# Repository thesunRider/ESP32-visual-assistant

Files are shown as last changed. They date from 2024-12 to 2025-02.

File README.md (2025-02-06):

# ESP32 AI portable visual-assistant  
### Device Design Requirements:

1. **Audio Playback:**
   - Play audio through a speaker using the Audio BFF amplifier.
   - Include necessary components for driving the speaker.

2. **Battery Charging:**
   - Support rechargeable Li-ion/Li-poly battery integration with efficient charging and power management.
   - Include a charging circuit and IC for managing charging and power distribution to the ESP32-S3.

3. **Connectivity:**
   - Enable Wi-Fi and Bluetooth (including BLE) for app connectivity and efficient power use.

4. **Camera Integration:**
   - Integrate an OV2640 camera module for image and video capture.

5. **Microphone and Control:**
   - Include three tactile buttons for microphone control with LED feedback for status (e.g., mute/unmute).

6. **Enclosure:**
   - Design a compact, 3D-printed enclosure with ports (e.g., USB charging) and provisions for heat dissipation.

# Final Product:
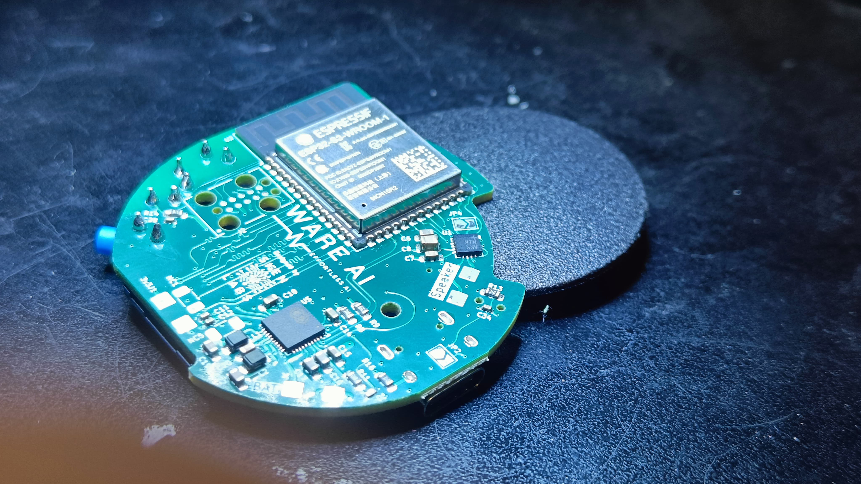
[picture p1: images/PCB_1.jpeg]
PCB_1

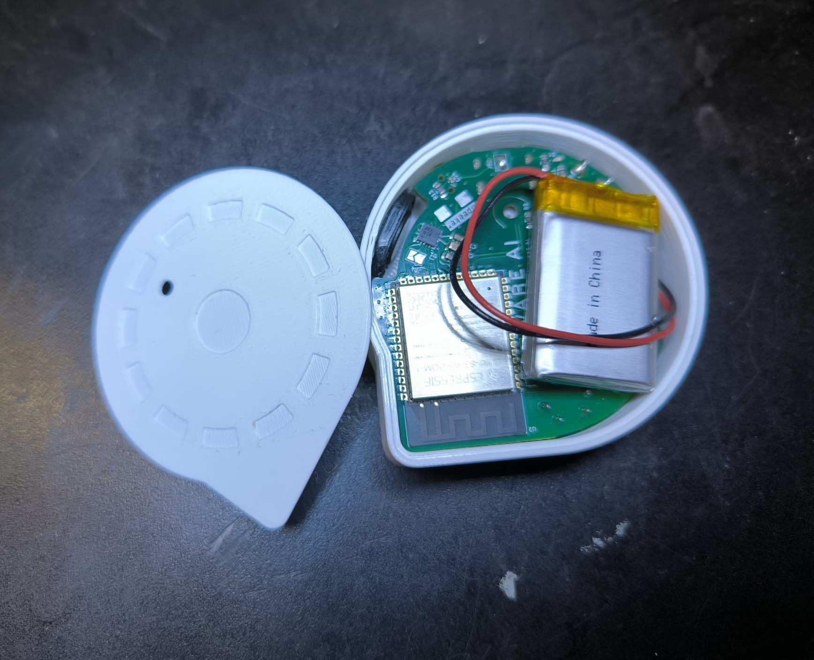
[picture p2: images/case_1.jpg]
Case_1


## Technicals
Language: C++ -> Need to create testcases for harware \
Folder Structure :
- Kicad
	- Test (First Prototype)
	- Main (Main Prototype)
- Docs
	- Datasheets
	- Images
- Gerbers

## Technology Used
Listing of Technologies used in the design:
- PMIC - [AXP2101](https://jlcpcb.com/partdetail/x_powersTech-AXP2101/C3036461) 
- Amplifier & Speaker  - [Max98357 Amplifier](https://learn.adafruit.com/adafruit-max98357-i2s-class-d-mono-amp/overview)
- Switches -
- Camera - [OV5640](https://www.waveshare.com/ov5640-camera-board-a.htm)
- Microphone - [Mems Mic](https://learn.adafruit.com/adafruit-i2s-mems-microphone-breakout/)
- Main Unit - [ESP32-S3-WROOM-1-N4](https://www.digikey.de/de/products/detail/espressif-systems/ESP32-S3-WROOM-1-N4/16163950)

## Flowchart

## Energy Charts

While connecting the amplifier , the supply to the amp should go just after the fuel gauge and the over current protection circuit 

| Component | Voltage  | Current  |
|---|---|---|
| Esp32 S3  | 3v3	 | 650mA |
| Mic | 3v3 | 2mA |
| Amp | 3v7 | 500mA |
| Camera | 3v3 , 2v8, 1v5 | 200mA |
| LED 		| 3v3	| 70mA	|
| Extras |3v3 |30mA|

Max current: 1.5A

## Notes
1. Kindly create a seperate page for each new design block (power, camera,mic,...etc) in kicad
2. Kindly Name no connect jumpers as 0ohm resistors and reference as NC
3. BE CAREFUL TO PLACE NC RESISTORS ISOLATED IN FOOTPRINT AS THEY NEED TO BE DESOLDERED OR SOLDERED WITHOUT DISTURBING SURROUNDINGS
4. Refer [Design Considerations](DesignConsideration.md) for specific module requirements
5. Crossrefer pinconnections between footprint and datasheet to check if they are the same.
6. CHECK IF ALL I2S, I2C , SPI AND SDA INTERFACES HAVE PROPER PULLUPS INSTALLED ON SCHEMATIC
7. Breakout a JTAG controller for debugging esp32

## TODO
- [x] Create Kicad Project
- [x] Make BMC and Avail power Rails
- [x] Craete Flowchart
- [x] Create Esp32 Base 
- [x] Create Amp Schematic
- [x] Create Mic Schematic
- [x] Create Camera Schematic - Created a symbol in Kicad for testing (proceeding with it - need reverse engineer testing)
- [x] Add switch Schematic
- [x] Link Components to PCB 
- [x] Test Cases for Hardware

Project Finished Rev2 Board created with superior perfomance

## Reference
Kindly put circuit reference here
1. USB from here: https://github.com/jenschr/USB-C-Connectors
2. PMIC Reference Design https://oshwhub.com/mondraker/axp2101_2023-11-18_20-15-19

## Components Sourcing
Adafruit OV5640 Camera Breakout
-  Breakout Board uses FD5640 500W Camera sensor
-  Available in bluk from Aliexpress
- Switch: K2-1114SA-A4SW-06, https://jlcpcb.com/partdetail/OmronElectronics-B3S1000/C2733655 Check pin configs
- Switch: K2-1114SA-A4SW-06, https://jlcpcb.com/partdetail/OmronElectronics-B3S1000/C2733655
- Speakers , https://www.lcsc.com/product-detail/Speakers_INGHAi-GSPK151035PN-8R0-5W-L35-1-25T_C530539.html
- Tactile Switches https://de.aliexpress.com/item/32912259140.html?gatewayAdapt=glo2deu

AXP2101 Component
- Inductor   3.1A 1uH ±20% 0806 Power Inductors ROHS
  https://www.lcsc.com/product-detail/Power-Inductors_Chilisin-Elec-HEI201610K-1R0M-Q8DG_C329576.html

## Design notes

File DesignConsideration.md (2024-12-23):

## Design Considerations
Here we specify all steps to produce each modules

## Technology Used
Listing of Technologies used in the design:
- ChargingBMC (PMIC) - [AXP2101](https://jlcpcb.com/partdetail/x_powersTech-AXP2101/C3036461) 
- Overvoltage Current protection
- Amplifier & Speaker  - [Max98357 Amplifier](https://learn.adafruit.com/adafruit-max98357-i2s-class-d-mono-amp/overview)
- Switches -
- Camera - OV5640 
- Microphone - [Mems Mic](https://learn.adafruit.com/adafruit-i2s-mems-microphone-breakout/)
- Main Unit - [ESP32-S3-WROOM-1-N4](https://www.digikey.de/de/products/detail/espressif-systems/ESP32-S3-WROOM-1-N4/16163950)

### ESP32 Module 
Unit: **ESP32-S3-WROOM-1-N4** \
JLCPCB: Not Available \
Logic levels ESP32 - VDD x 0.75 H : VDD x 0.25 L \
Max 650 mA at 3.3V input 

- Soldering the EPAD to the ground of the base board is not a must, however, it can optimize thermal
performance. If you choose to solder it, please apply the correct amount of soldering paste. Too much
soldering paste may increase the gap between the module and the baseboard. As result, the adhesion
between other pins and the baseboard may be poor.

- To ensure that the power supply to the ESP32-S3 chip is stable during power-up, it is advised to add an
RC delay circuit at the EN pin. The recommended setting for the RC delay circuit is usually R = 10 kΩ and
C = 1 µF. However, specific parameters should be adjusted based on the power-up timing of the module
and the power-up and reset sequence timing of the chip. For ESP32-S3’s power-up and reset sequence
timing diagram, please refer to ESP32-S3 Series Datasheet > Section Power Supply

For booting after reset:

| Boot Mode | GPIO0  | GPIO46  |
|---|---|---|
| SPI Boot  | 1	 | Any |
| Joint Boot | 0 | 0 |

SPI Boot - Loads from internal memory and executes (default)
Joint Boot - In Joint Download Boot mode, users can download binary files into flash using UART0 or USB interface. It is
also possible to download binary files into SRAM and execute it from SRAM (Programming)

#### Warning
- IO47/IO48 operates in the 1.8V voltage domain.

## Microphone Module
Unit: ICS-43434 \
JLCPCB: Available \
Logic Levels: VDD x 0.7 H : VDD x 0.3 L \
Max 1mA at 3.3V \
I2S unit with full itegrated components 

Refer App notes \
Refer Schematic at: https://learn.adafruit.com/assets/132616 \

### Warning
- SD Output Serial	Data Output	for	I²S	Interface.	This	pin	tristates	when	not	actively	driving	the	
appropriate	output	channel.	The	SD	trace	should	have	a	100	kΩ	pull-down	resistor	to	
discharge	the	line	during	the	time that	all	microphones	on	the	bus	have	tristated	their	
outputs.	

### Interfacing
ESP32-S3 includes two standard I2S interfaces. They can operate in master mode or slave mode, in full-duplex mode or half-duplex communication mode, and can be configured to operate with an 8-bit, 16-bit, 24-bit, or 32-bit resolution as an input or output channel. BCK clock frequency, from 10 kHz up to 40 MHz, is supported.

The I2S interface has a dedicated DMA controller. It supports TDM PCM, TDM MSB alignment, TDM LSB alignment, TDM Phillips, and PDM interface.
Pin Assignment:
For I2S, the pins used can be chosen from any GPIOs via the GPIO Matrix. For more information about the pin assignment, see ESP32-S3 Series Datasheet > Section IO Pins and ESP32-S3 Technical Reference Manual > Chapter IO MUX and GPIO Matrix.

## Amplifier and Speaker
Unit: MAX98357 \ 
JLCPCB: Available \
Logic Levels: 1.3 H : 0.6V L \
Max 500mA at 3.7V 

I2S unit with full itegrated components \
The gain of the unit depends on the Resistor connected to Gainslot

| GAIN_SLOT |  I2S/LJ GAIN (dB)  |
|---|---|
| Connect to GND through 100kΩ  | 15	 | 
| Connect to GND  | 12 | 
|Unconnected|9|
|Connect to VDD|6|
|Connect to VDD through 100kΩ|3|

Try changing NC2 according table above to increase/decrease gain

### Warning
The amplifier only TAKES LEFT CHANNEL \

## Camera 
Unit: OV5640 \
JLCPCB: Not available \
Logic Levels: 2.8V \
core: 1.5V ± 5% (with embedded 1.5V regulator) \
analog: 2.6 ~ 3.0V (2.8V typical) \
I/O: 1.8V / 2.8V \
Power: active: 140 mA 

Connector : 24 Pin 0.5mm Pitch Bottom Contact ZIF Connector,FPC Connector - https://www.buydisplay.com/24-pin-0-5mm-pitch-bottom-contact-zif-connector-fpc-connector

### Warning: 
While connecting camera module there are a lot of unconnected jumpers ,while testing check if we need connection by refering schematic (BUY 0ohm resisors) 

## Charging and PMIC
Unit: AXP2101 \
JLCPCB: available \
Logic level: 3.3V 

## Color LED 
Unit: WS2812B \
JLCPCB: Avaialble \
Logic Level: 0.7 x VCC H : 0.3 x VCC L \
Min 3.5V with 60mA \

## ESD Protection
Status Pending

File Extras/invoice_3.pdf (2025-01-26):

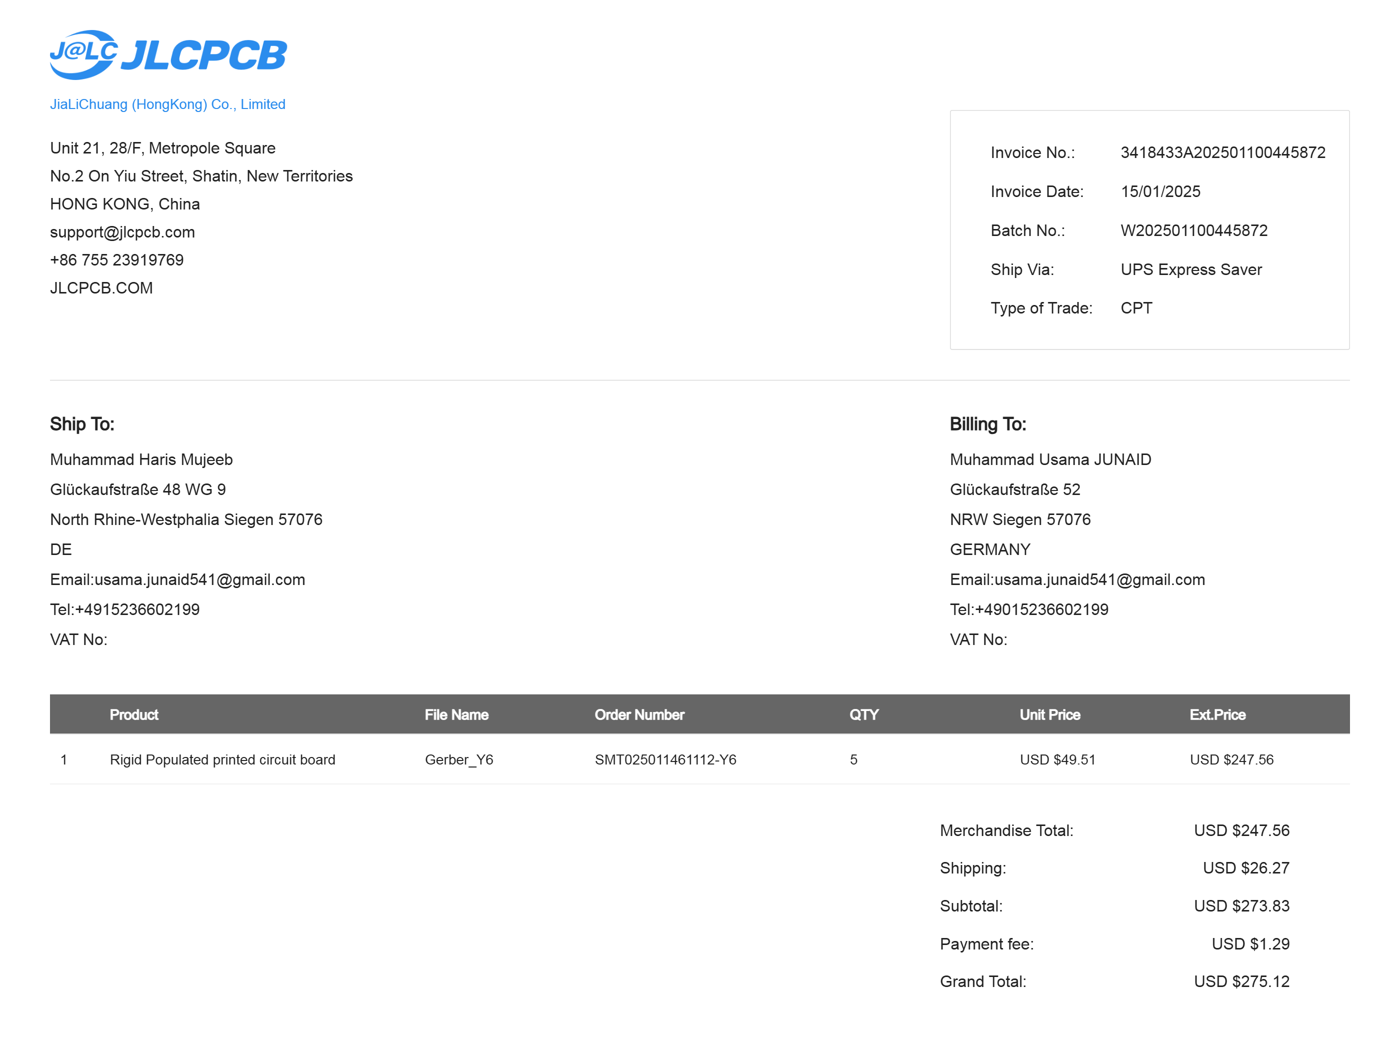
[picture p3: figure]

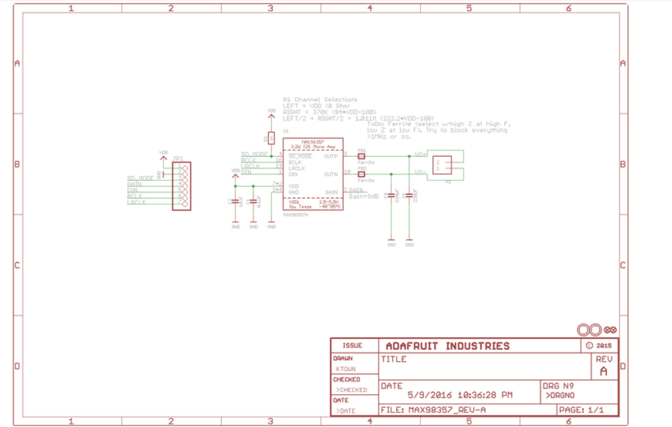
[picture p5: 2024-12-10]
Docs/Reference Schematic/max98357A.PNG

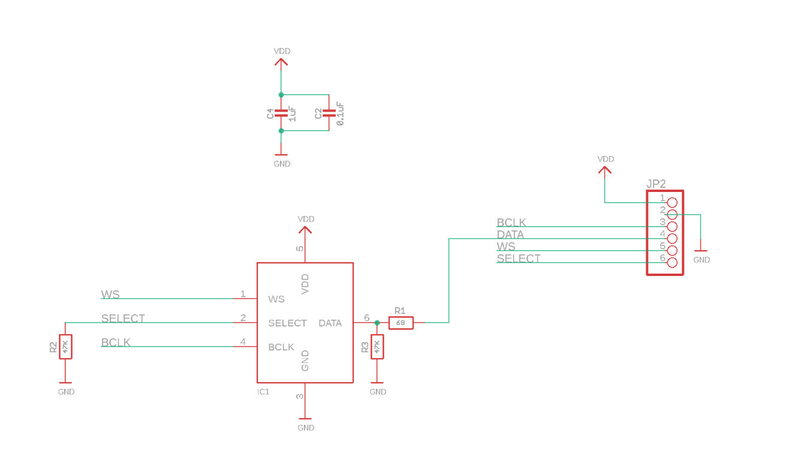
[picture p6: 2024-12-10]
Docs/Reference Schematic/ics43434.PNG

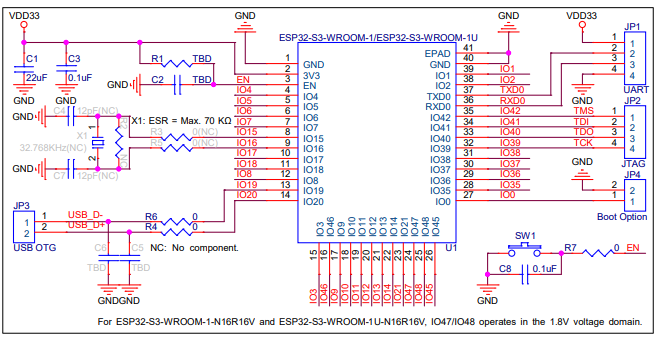
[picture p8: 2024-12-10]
Docs/Reference Schematic/esp32s3_peripherals.PNG

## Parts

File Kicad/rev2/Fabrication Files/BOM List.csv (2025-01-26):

null | Designator | Value | Footprint | Description | LCSC Part # | Mfr Part | Quantity
1 | C10, C11, C12, C13, C27, C28, C29, C30, C31, C34 | 100n | C_0402_1005Metric | Unpolarized capacitor | C1525 | CL05B104KO5NNNC | 10 | 16V 100nF X7R ±10% 0402 Multilayer Ceramic Capacitors MLCC - SMD/SMT ROHS
2 | C2, C4, C6, C16, C17, C19, C22 | 22u | C_0603_1608Metric_Pad1.08x0.95mm_HandSolder | Unpolarized capacitor | C59461 | CL10A226MQ8NRNC | 7 | 6.3V 22uF X5R ±20% 0603 Multilayer Ceramic Capacitors MLCC - SMD/SMT ROHS
3 | C15, C18, C20, C21,C23, C25, C26, | 10u | C_0603_1608Metric_Pad1.08x0.95mm_HandSolder | Unpolarized capacitor | C19702 | CL10A106KP8NNNC | 6 | 10V 10uF X5R ±10% 0603 Multilayer Ceramic Capacitors MLCC - SMD/SMT ROHS
4 | C3, C5, C7 | 0.1u | C_0603_1608Metric_Pad1.08x0.95mm_HandSolder | Unpolarized capacitor | C14663 | CC0603KRX7R9BB104 | 3 | 50V 100nF X7R ±10% 0603 Multilayer Ceramic Capacitors MLCC - SMD/SMT ROHS
5 | C9, C33 | 15p | C_0402_1005Metric | Unpolarized capacitor | C1548 | 0402CG150J500NT | 2 | 50V 15pF C0G ±5% 0402 Multilayer Ceramic Capacitors MLCC - SMD/SMT ROHS
6 | C1, C14, C24 | 1u | C_0603_1608Metric | Unpolarized capacitor | C15849 | CL10A105KB8NNNC | 3 | 50V 1uF X5R ±10% 0603 Multilayer Ceramic Capacitors MLCC - SMD/SMT ROHS
7 | C8 | 100u | C_0603_1608Metric_Pad1.08x0.95mm_HandSolder | Unpolarized capacitor | C141660 | GRM21BR60J107ME15L | 1 | 6.3V 100uF X5R ±20% 0805 Multilayer Ceramic Capacitors MLCC - SMD/SMT ROHS
9 | R1, R8, R9, R12, R13, R14, R15 | 10k | R_0603_1608Metric_Pad0.98x0.95mm_HandSolder | Resistor | C25804 | 0603WAF1002T5E | 7 | 100mW Thick Film Resistors 75V ±100ppm/? ±1% 10k? 0603 Chip Resistor - Surface Mount ROHS
10 | R2, R3 | 47k | R_0603_1608Metric_Pad0.98x0.95mm_HandSolder | Resistor | C25819 | 0603WAF4702T5E | 2 | 100mW Thick Film Resistors 75V ±100ppm/? ±1% 47k? 0603 Chip Resistor - Surface Mount ROHS
11 | R7, R10 | 4.7k | R_0603_1608Metric_Pad0.98x0.95mm_HandSolder | Resistor | C23162 | 0603WAF4701T5E | 2 | 100mW Thick Film Resistors 75V ±100ppm/? ±1% 4.7k? 0603 Chip Resistor - Surface Mount ROHS
12 | R4 | 68 | R_0603_1608Metric_Pad0.98x0.95mm_HandSolder | Resistor | C27592 | 0603WAF680JT5E | 1 | 100mW Thick Film Resistors 75V ±100ppm/? ±1% 68? 0603 Chip Resistor - Surface Mount ROHS
13 | R11 | 1k | R_0603_1608Metric_Pad0.98x0.95mm_HandSolder | Resistor | C21190 | 0603WAF1001T5E | 1 | 100mW Thick Film Resistors 75V ±100ppm/? ±1% 1k? 0603 Chip Resistor - Surface Mount ROHS
14 | R16 | 1M | R_0603_1608Metric_Pad0.98x0.95mm_HandSolder | Resistor | C22935 | 0603WAF1004T5E | 1 | 100mW Thick Film Resistors 75V ±100ppm/? ±1% 1M? 0603 Chip Resistor - Surface Mount ROHS
15 | L1, L2 | 1u | L_0805_2012Metric_Pad1.05x1.20mm_HandSolder | Inductor | C6364721 | AHW2012F-1R0KTF | 2 | 430mA 1uH ±10% 1? 0805 Inductors (SMD) ROHS
16 | D1 | LED | LED_0402_1005Metric | Light emitting diode | C965793 | XL-1005UGC | 1 | 25mA 249mcd Colorless transparent lens -30?~+85? Positive Stick 516nm~531nm Emerald 120° 80mW 3V 0402 LED Indication - Discrete ROHS
17 | D4 | WS2812B | LED_WS2812B_PLCC4_5.0x5.0mm_P3.2mm | RGB LED with integrated controller | C22461793 | XL-5050RGBC-WS2812B-S | 1 | SMD-4P,5x5mm RGB LEDs(Built-in IC) ROHS
18 | U1 | MAX98357A | TQFN-16-1EP_3x3mm_P0.5mm_EP1.23x1.23mm | Monaural 3.2Wx2@4Î© BGA-9(1.3x1.3) Audio Amplifiers ROHS | C2682619 | MAX98357AEWL+T | 1
19 | U2 | ESP32-S3-WROOM-1 | ESP32-S3-WROOM-1 | RF Module, ESP32-S3 SoC, Wi-Fi 802.11b/g/n, Bluetooth, BLE, 32-bit, 3.3V, onboard antenna, SMD | C2913205 |  | 1
20 | U3 | OV5640 | TE_2-1734839-4_1x24-1MP_P0.5mm_Horizontal | Flip type 24P Bottom Contact Horizontal attachment 0.5mm SMD,P=0.5mm,Surface Mountï¼ŒRight Angle FFC, FPC (Flat Flexible) Connector Assemblies ROHS | C262669 | AFC01-S24FCA-00 | 1
21 | U4 | 24Mhz | YSO110TR | 1.8V~3.3V Â±10ppm 4mA Â±20ppm CMOS 24MHz SMD2520-4P Crystal Oscillators ROHS | C669072 | OT252024MJBA4SL | 1
22 | U5 | AXP2101 | QFN-40-1EP_5x5mm_P0.4mm_EP3.6x3.6mm | QFN-40-EP(5x5) Power Management - Specialized ROHS | C3036461 | AXP2101 | 1
23 | SW1, SW2 | SW_Push | SW2_1825027-C_TEC | 3.25mm Round Button 50mA Bend-in SPST 160gf 24V Plugin Tactile Switches ROHS | C266196 | 1825027-8 | 2
24 | SW4 | SW_Push | K2-1114SA-A4SW-06 | 3.5mm 1.65mm Rectangle button 50mA Horizontal attachment 4.8mm SPST 100000 Times 250gf 12V SMD Tactile Switches ROHS | C136662 | K2-1114SA-A4SW-06 | 1
25 | SW5 | SW_Push | SW_SPST_B3S-1000 | Tactile Switches ROHS | C2733655 | B3S-1000 | 1
27 | JP2, JP3, JP4 | Jumper | SolderJumper-2_P1.3mm_Open_TrianglePad1.0x1.5mm | Jumper, 2-pole, open |  |  | 3
28 | NC1, NC3, NC5 | 0 | R_1206_3216Metric | Resistor |  |  | 3
29 | MK2 | ICS-43434 | InvenSense_ICS-43434-6_3.5x2.65mm | Omni-directional 64dB MEMS Microphones ROHS | C5656610 | ICS-43434 | 1
31 | P1 | USB_C_Plug_USB2.0 | USB_C_Receptacle_HRO_TYPE-C-31-M-12 | USB 2.0-only Type-C Plug connector | C2982555 | TYPE-C-31-M-14 | 1

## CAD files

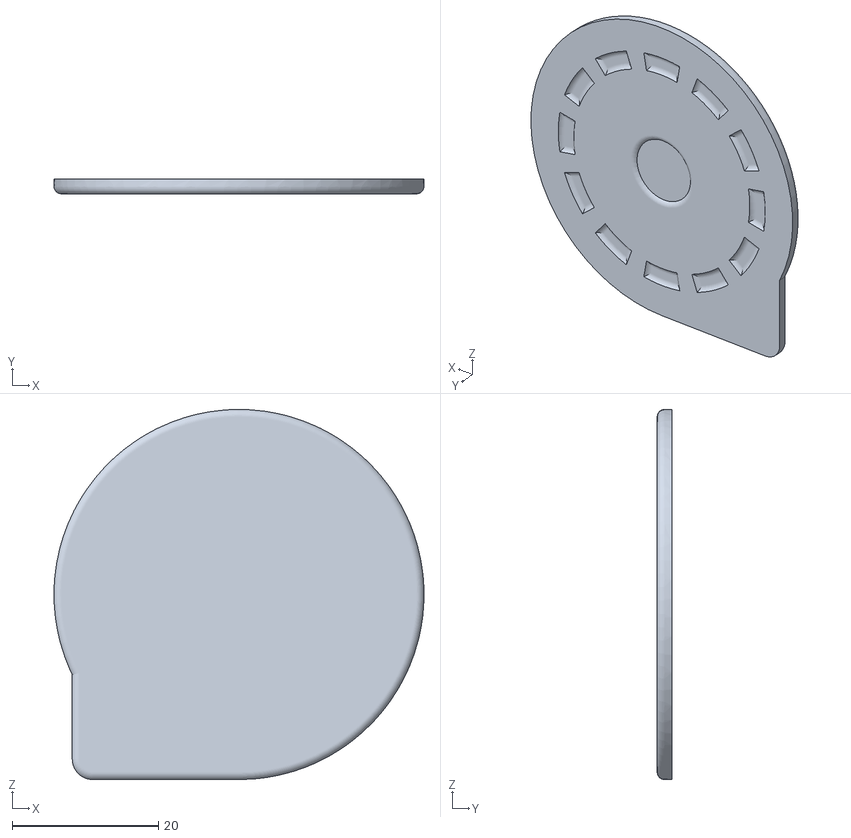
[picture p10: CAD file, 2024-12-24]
3d_model/Casing/Ware_lid.STL
50.6 x 2.00 x 50.6

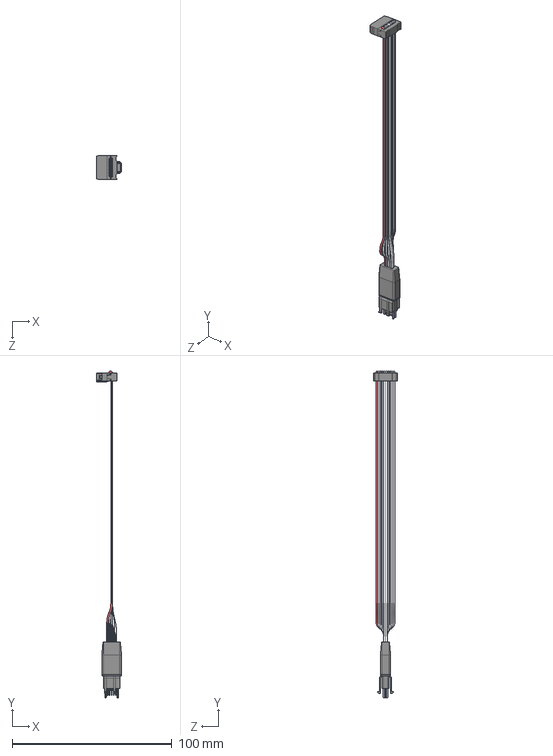
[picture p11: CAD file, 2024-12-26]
3d_model/TC2050-IDC.step
15.7 x 204.4 x 15.2 mm

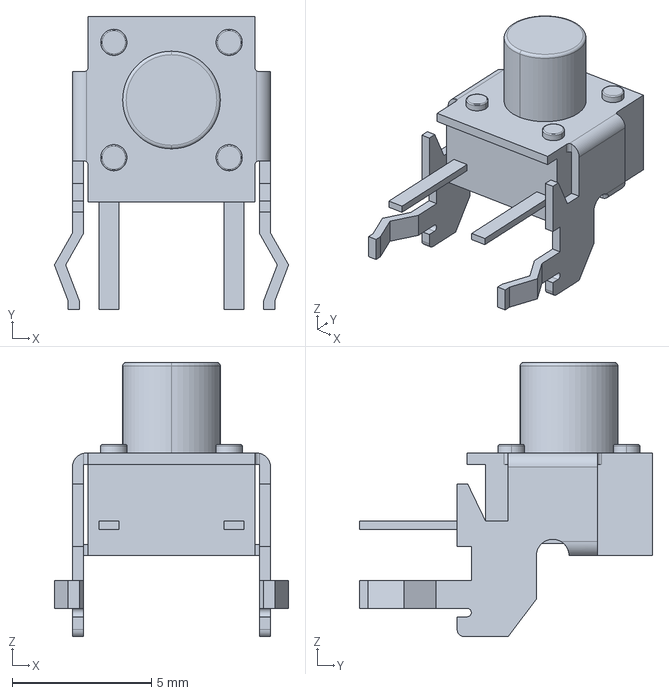
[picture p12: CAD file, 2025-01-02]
Kicad/ImportedComponents/c-1825027-8-g-3d.stp
8.41 x 10.5 x 9.84 mm

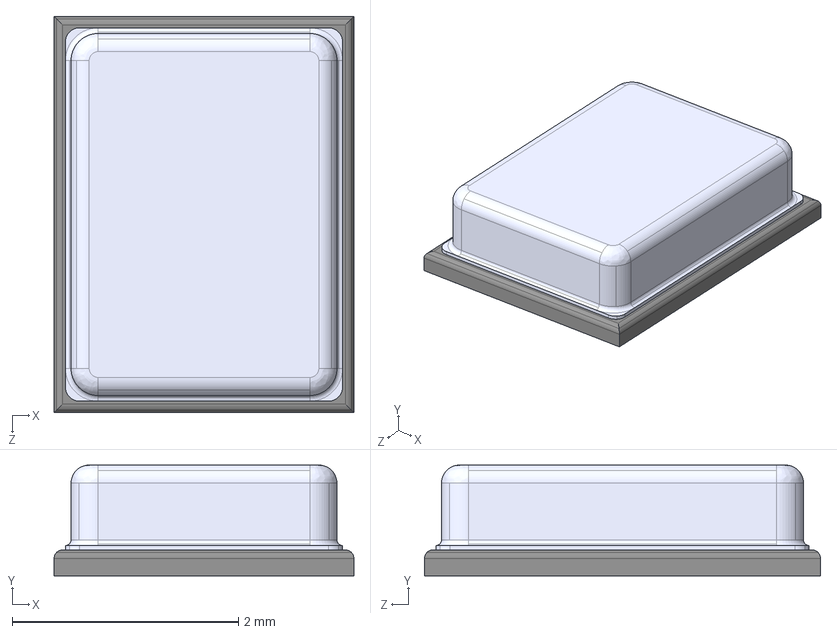
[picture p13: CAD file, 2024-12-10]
Kicad/ImportedComponents/ICS-43434/ICS-43434.step
2.65 x 0.98 x 3.50 mm

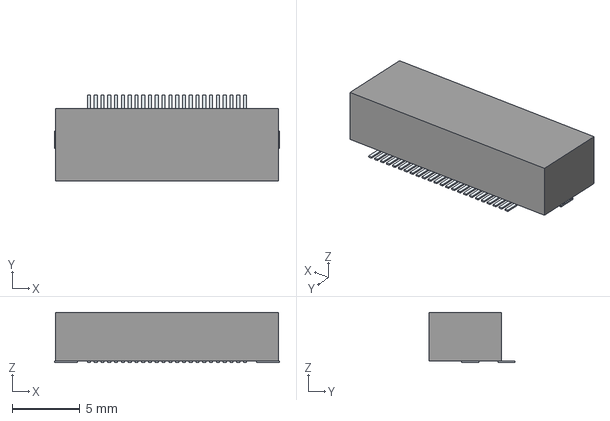
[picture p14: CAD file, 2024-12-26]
3d_model/AFC01-S24FCA-00.stp
16.6 x 6.32 x 3.70 mm
Pins

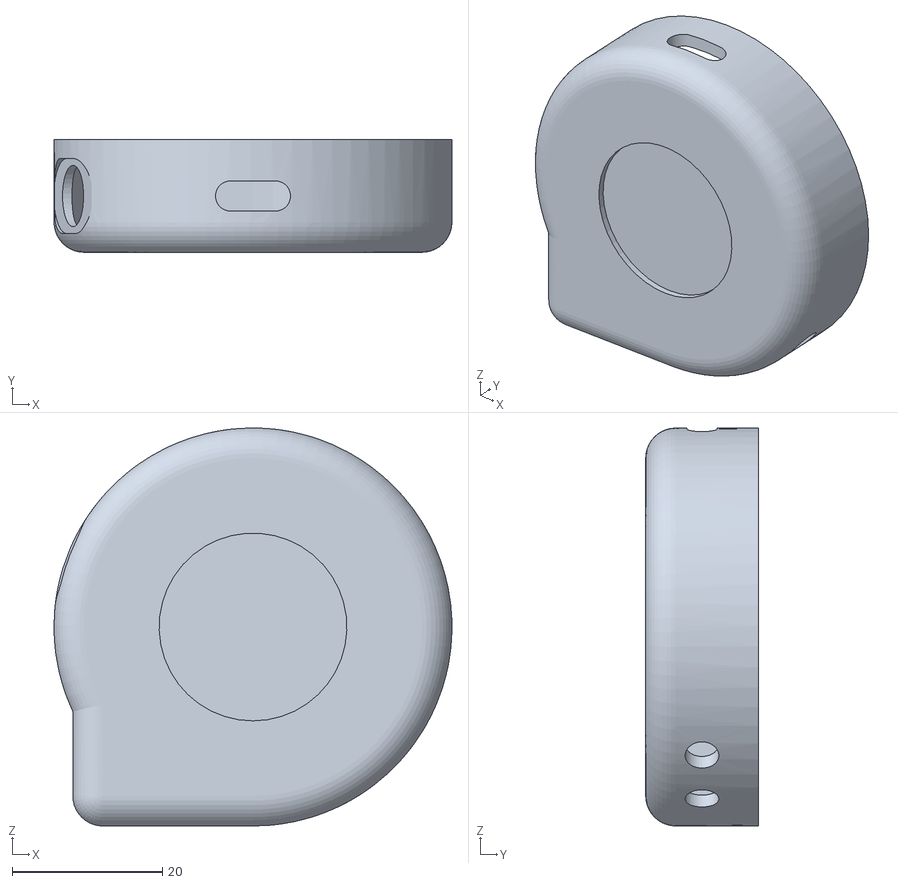
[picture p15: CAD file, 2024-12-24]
3d_model/Casing/Ware_outer_shell.STL
53.0 x 15.0 x 53.0

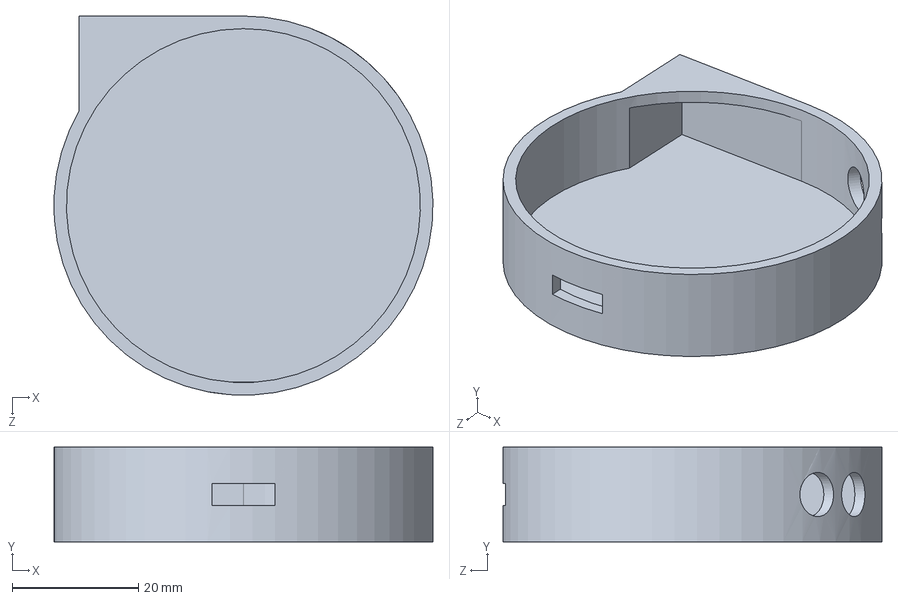
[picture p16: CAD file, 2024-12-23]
3d_model/Ware_outer_shell.SLDPRT
60.0 x 15.0 x 60.0 mm

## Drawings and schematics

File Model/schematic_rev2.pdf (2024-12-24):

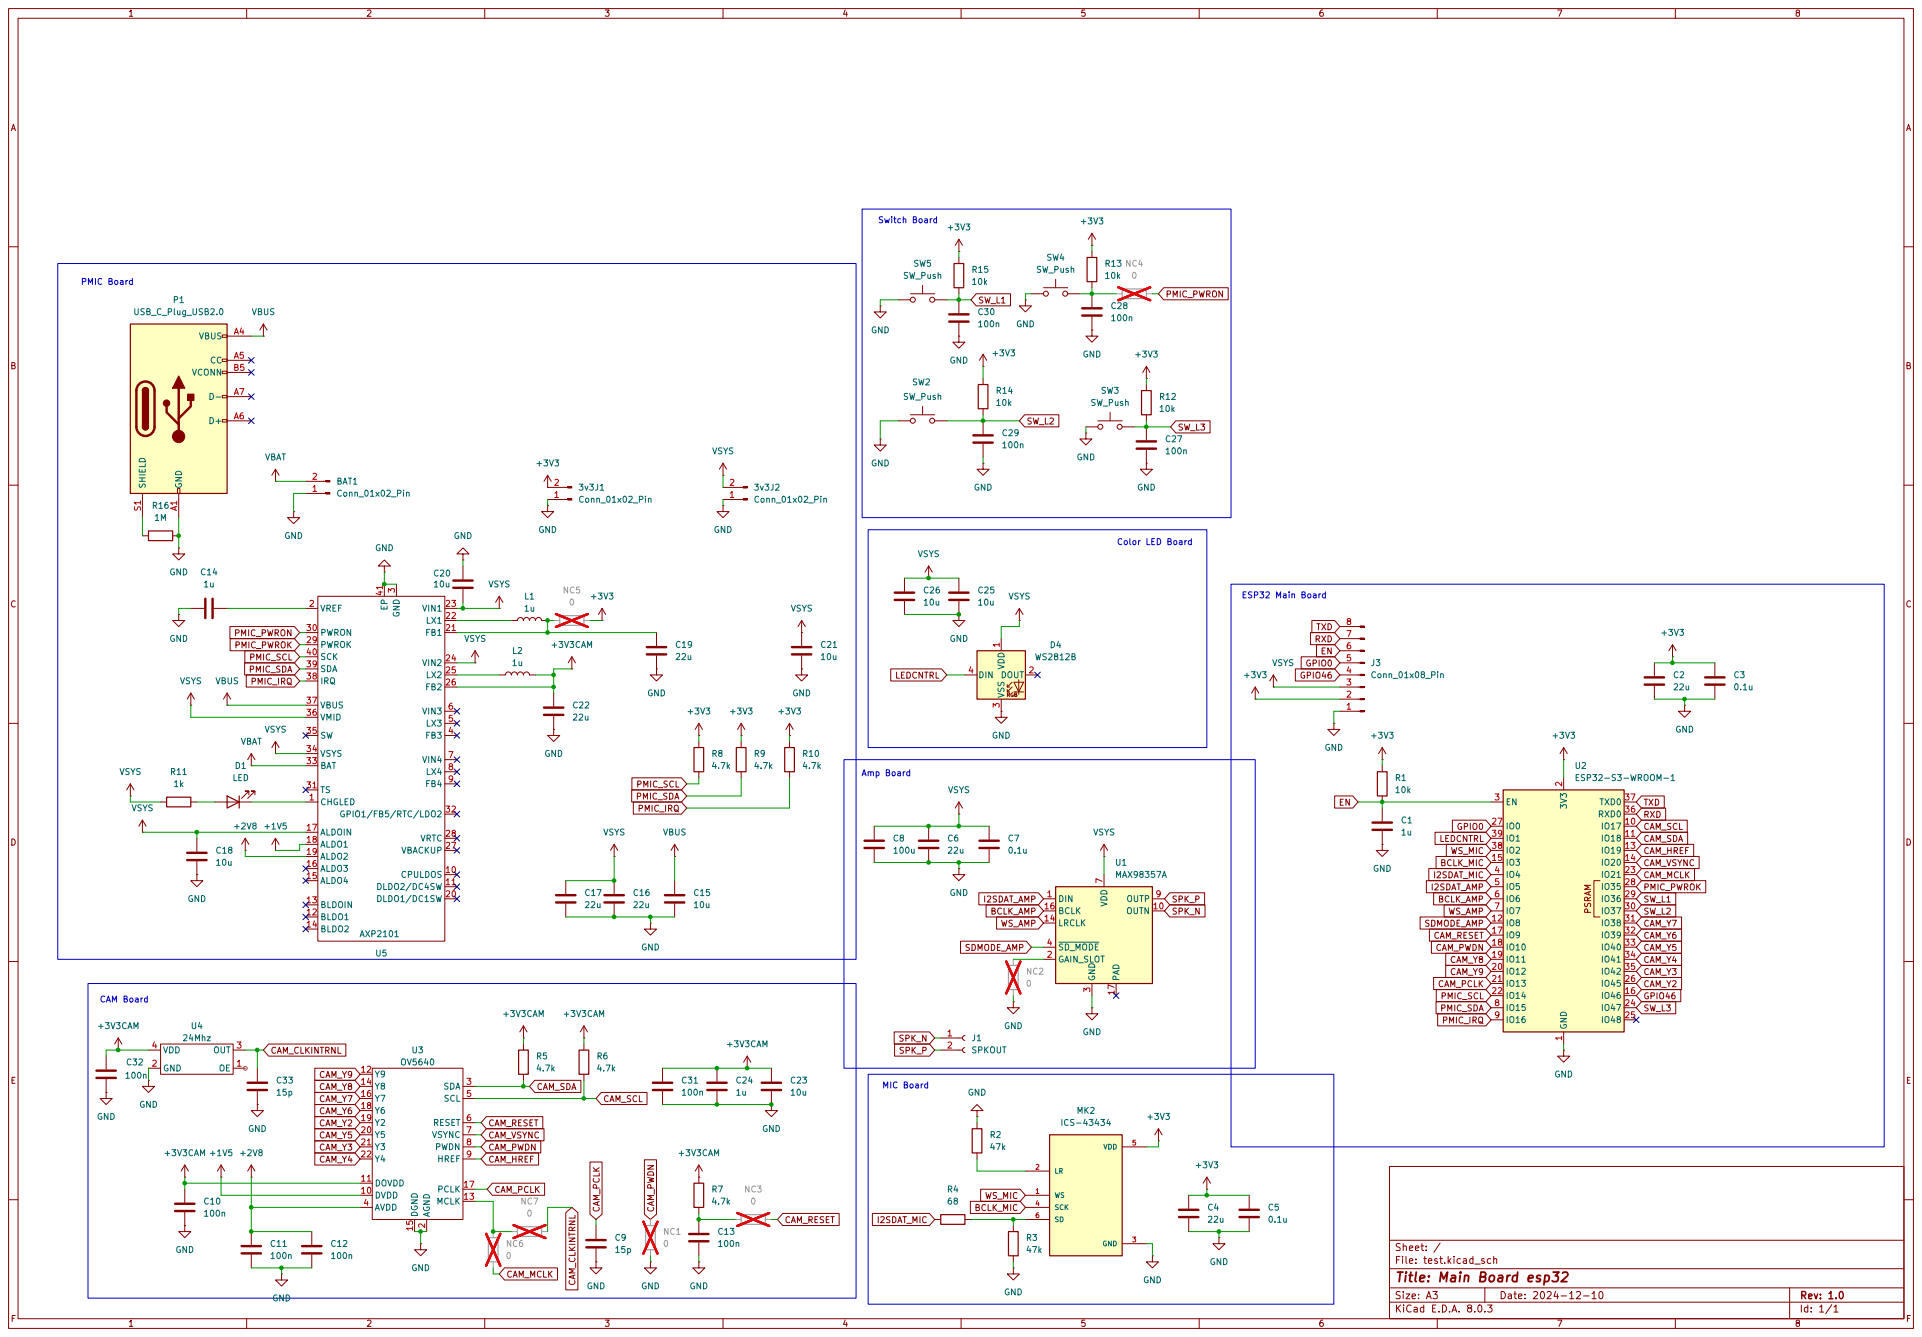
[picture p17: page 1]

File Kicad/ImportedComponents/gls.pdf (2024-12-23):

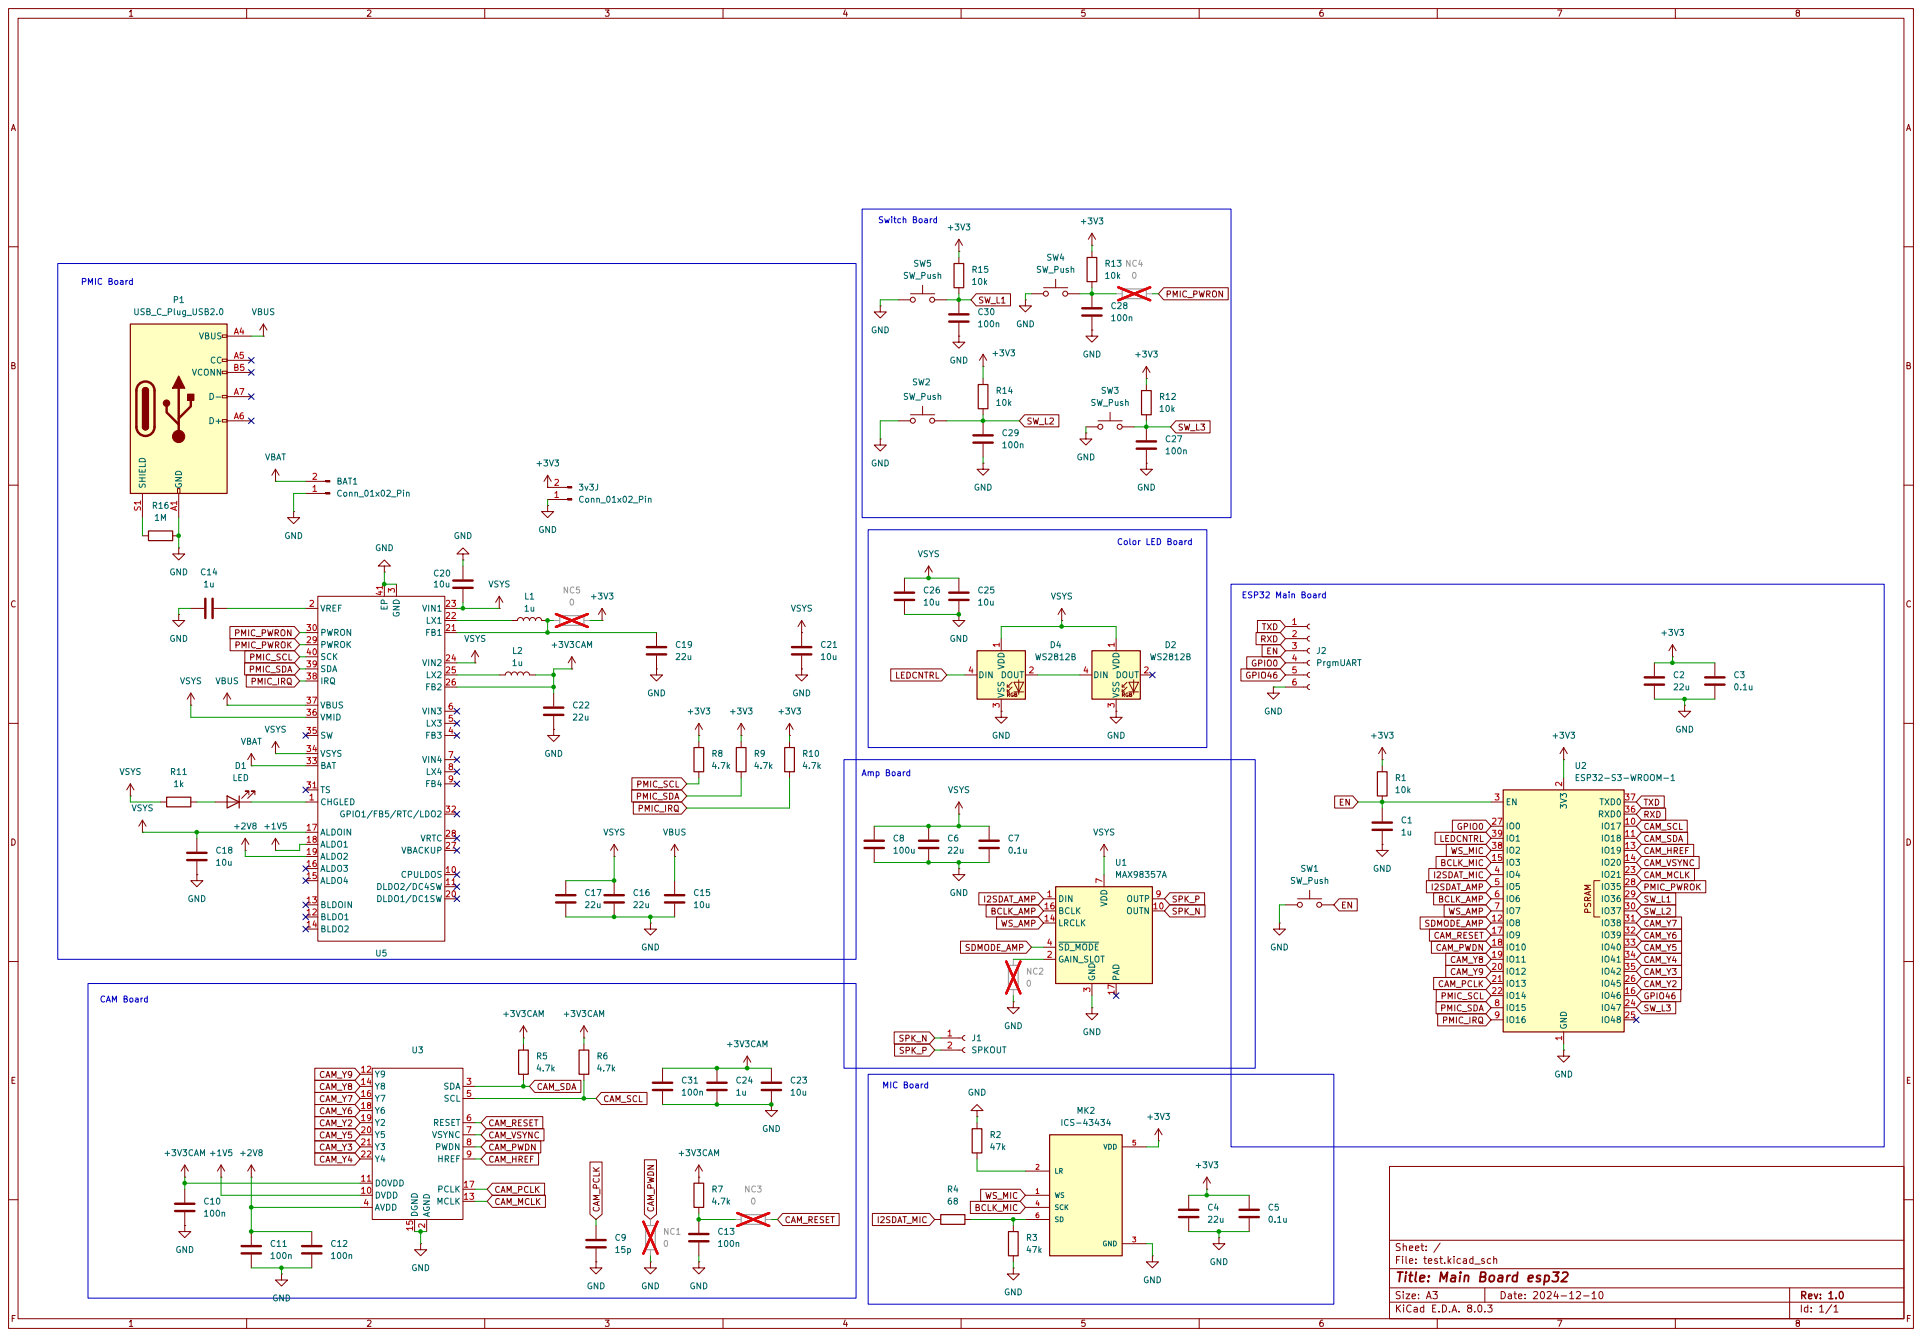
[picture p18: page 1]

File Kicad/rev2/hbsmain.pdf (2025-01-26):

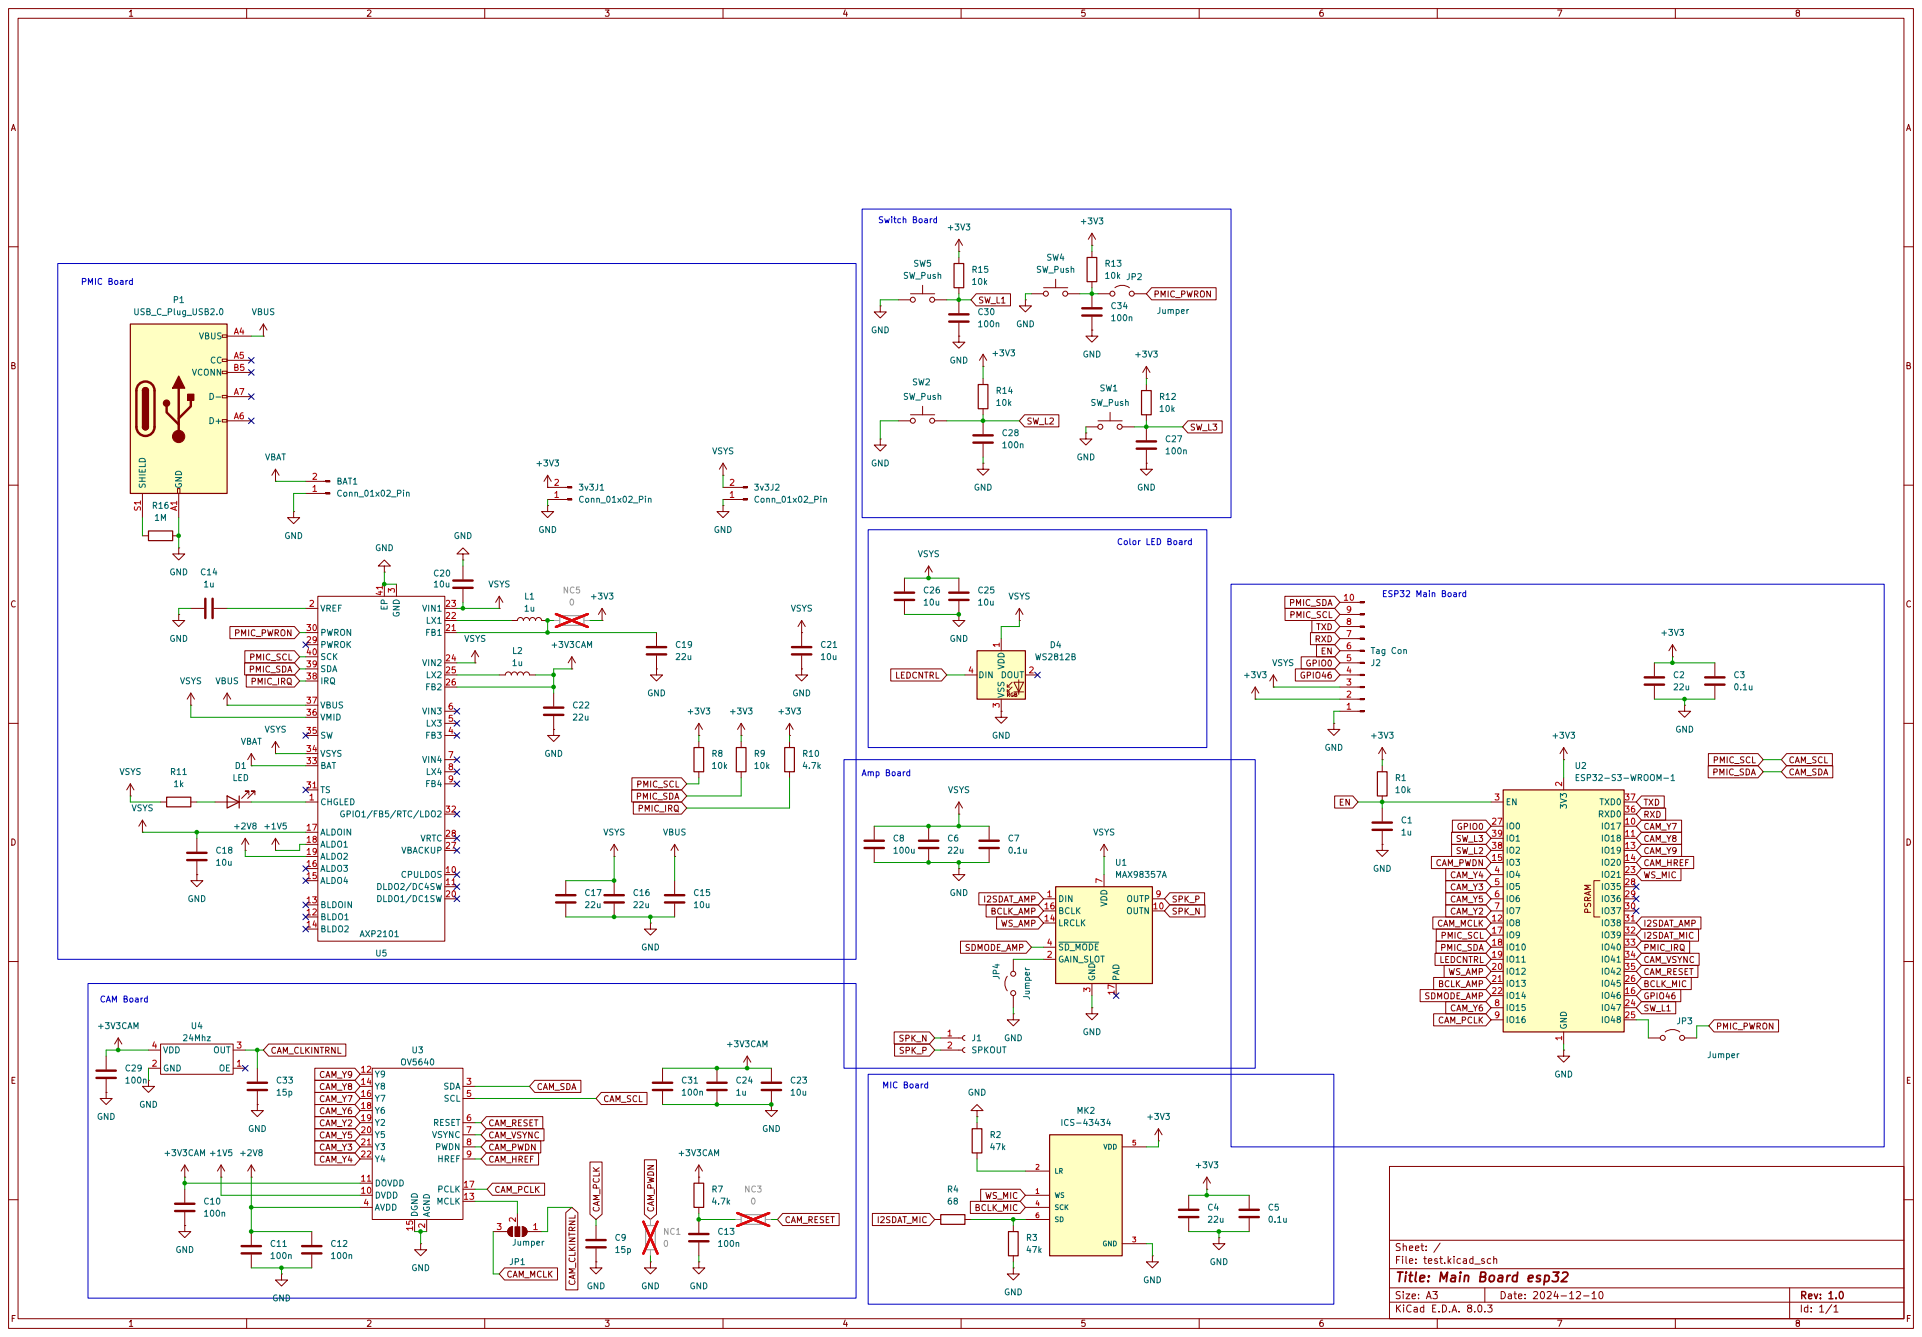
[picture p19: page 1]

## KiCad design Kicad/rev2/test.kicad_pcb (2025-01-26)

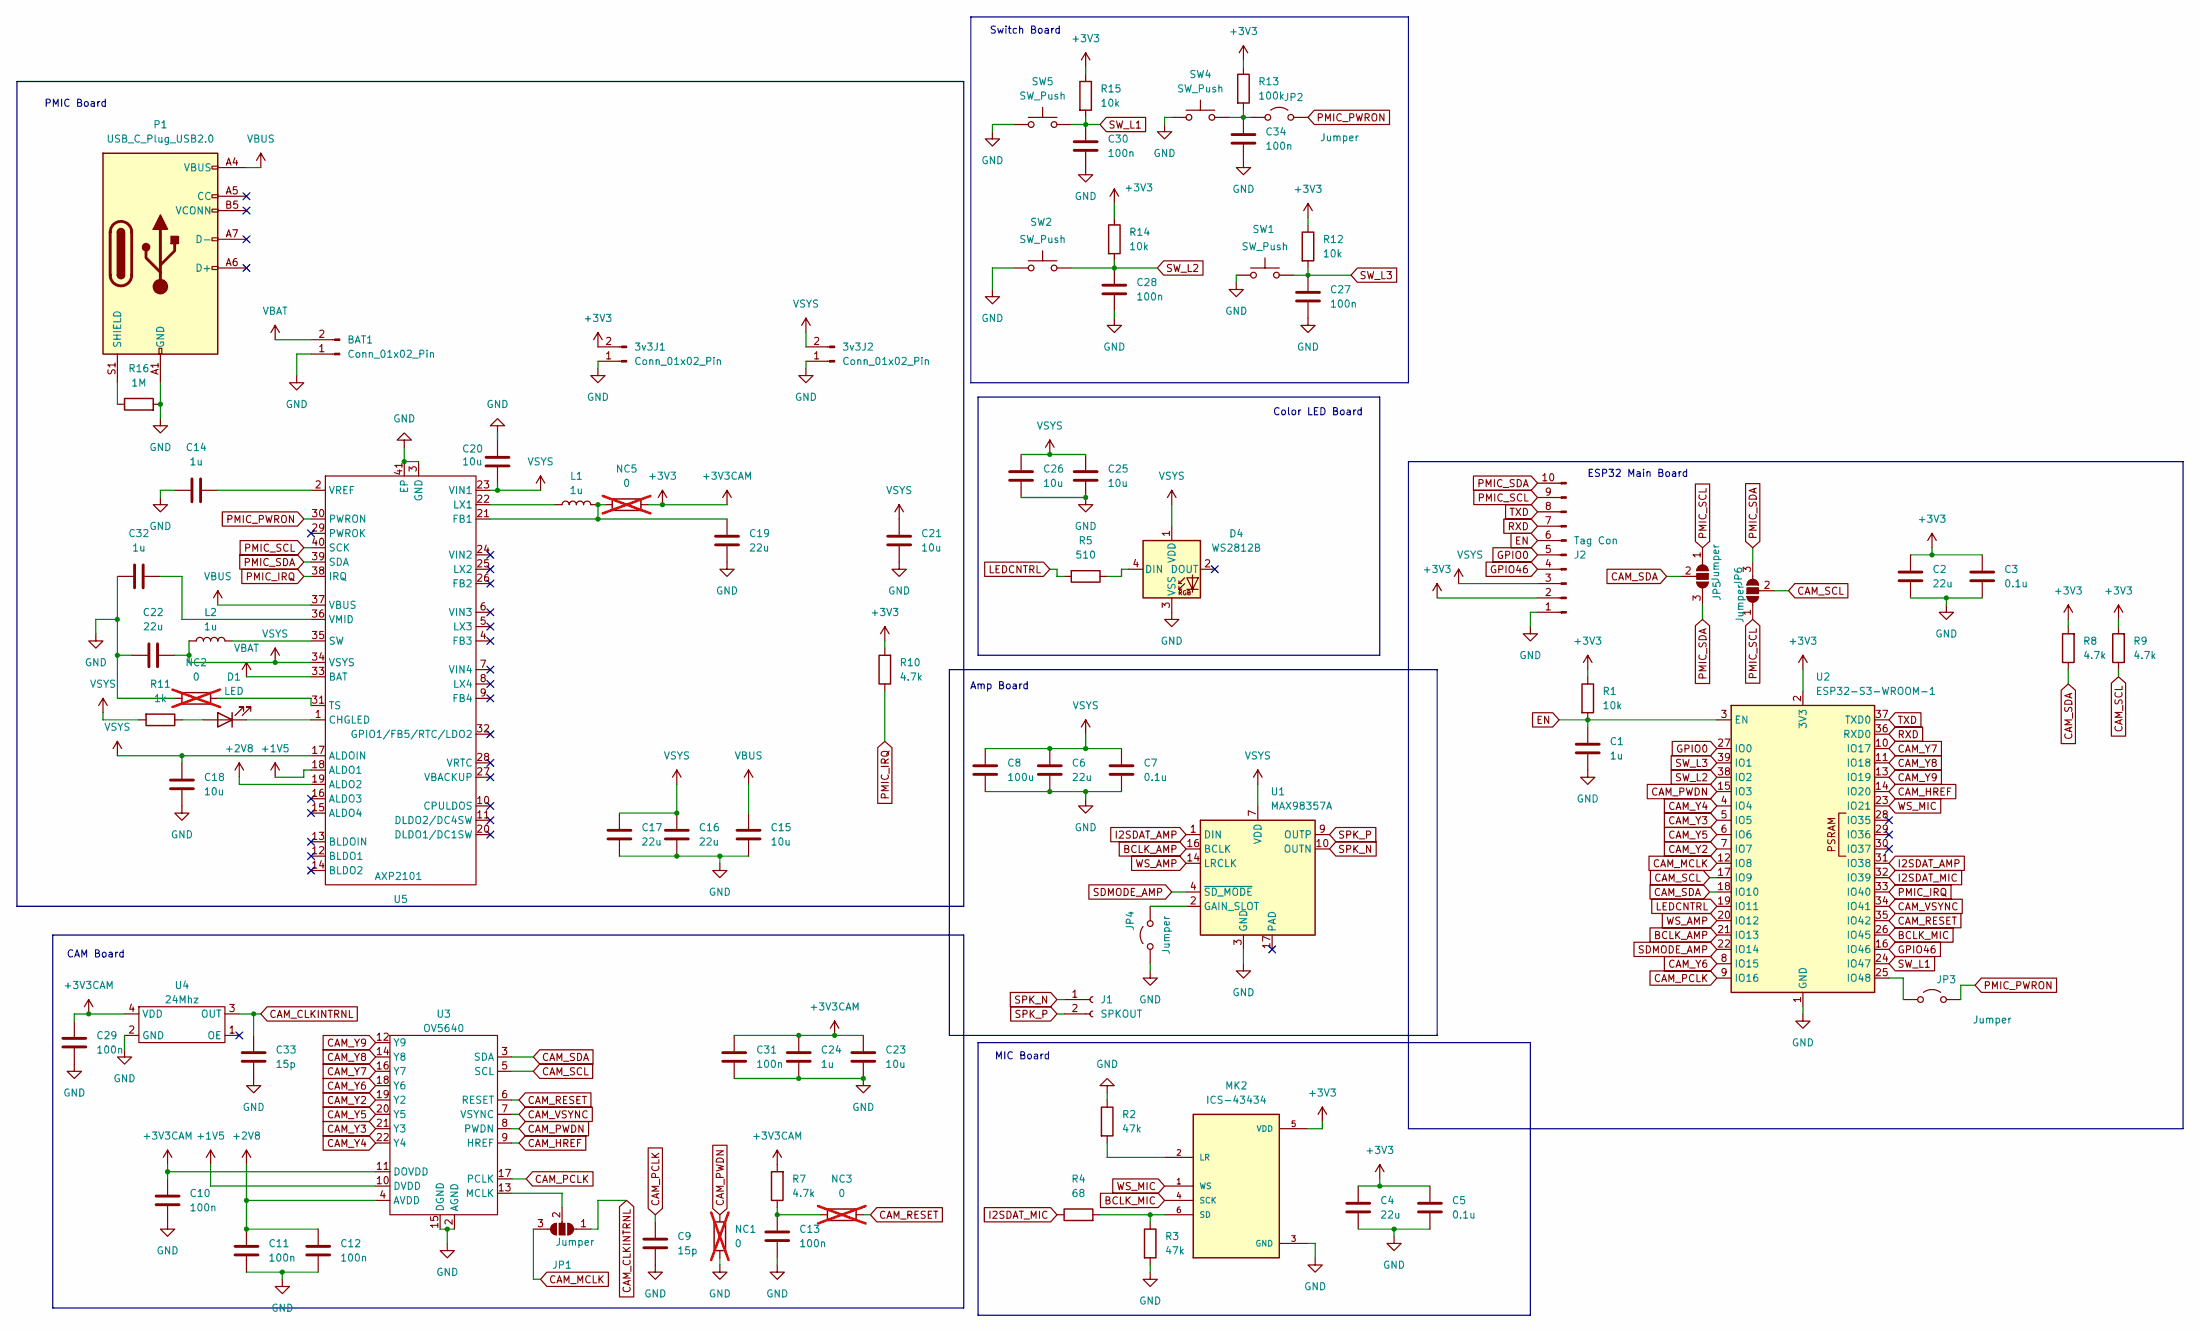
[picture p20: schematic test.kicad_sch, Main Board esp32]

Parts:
3v3J1, 3v3J2: Conn_01x02_Pin; SMD_CONNECTOR_PAD
BAT1: Conn_01x02_Pin; SMD_CONNECTOR_PAD
C1, C14, C24, C32: 1u; C_0603_1608Metric
C2, C4, C6, C16, C17, C19, C22: 22u; C_0603_1608Metric_Pad1.08x0.95mm_HandSolder
C3, C5, C7: 0.1u; C_0603_1608Metric_Pad1.08x0.95mm_HandSolder
C8: 100u; C_0805_2012Metric
C9, C33: 15p; C_0402_1005Metric
C10, C11, C12, C13, C27, C28, C29, C30, C31, C34: 100n; C_0402_1005Metric; Mfr. # CL05B104KO5NNNC; LCSC Part # C1525
C15, C18, C20, C21, C25, C26: 10u; C_0603_1608Metric_Pad1.08x0.95mm_HandSolder
C23: 10u; C_0603_1608Metric
D1: LED; LED_0402_1005Metric
D4: WS2812B; LED_WS2812B_PLCC4_5.0x5.0mm_P3.2mm; Mfr Part XL-5050RGBC-WS2812B-S; LCSC Part C22461793
J1: SPKOUT; SMD_CONNECTOR_PAD
J2: Tag Con; TAG-CONNECT_TC2050-IDC
JP1, JP5, JP6: Jumper; SolderJumper-3_P1.3mm_Open_RoundedPad1.0x1.5mm
JP2, JP3, JP4: Jumper; SolderJumper-2_P1.3mm_Open_TrianglePad1.0x1.5mm
L1, L2: 1u; L_0805_2012Metric_Pad1.05x1.20mm_HandSolder; Mfr Part AHW2012F-1R0KTF; LCSC Part C6364721
MK2: ICS-43434; InvenSense_ICS-43434-6_3.5x2.65mm; Mfr Part ICS-43434; LCSC Part C5656610
NC1, NC2, NC3, NC5: 0; R_1206_3216Metric; not fitted
P1: USB_C_Plug_USB2.0; USB_C_Receptacle_HRO_TYPE-C-31-M-12; Mfr Part TYPE-C-31-M-14; LCSC Part C223907
R1: 10k; R_0603_1608Metric
R2, R3: 47k; R_0603_1608Metric_Pad0.98x0.95mm_HandSolder
R4: 68; R_0603_1608Metric_Pad0.98x0.95mm_HandSolder
R5: 510; R_0603_1608Metric_Pad0.98x0.95mm_HandSolder
R7, R8, R9, R10: 4.7k; R_0603_1608Metric_Pad0.98x0.95mm_HandSolder
R11: 1k; R_0603_1608Metric_Pad0.98x0.95mm_HandSolder
R12, R14, R15: 10k; R_0603_1608Metric_Pad0.98x0.95mm_HandSolder
R13: 100k; R_0603_1608Metric_Pad0.98x0.95mm_HandSolder
R16: 1M; R_0603_1608Metric_Pad0.98x0.95mm_HandSolder
SW1, SW2: SW_Push; SW2_1825027-C_TEC; Mfr Part 1825027-8; LCSC Part C266196
SW4: SW_Push; K2-1114SA-A4SW-06; Mfr Part K2-1114SA-A4SW-06; LCSC Part C136662
SW5: SW_Push; SW_SPST_B3S-1000; Mfr Part B3S-1000; LCSC Part C2733655
U1: MAX98357A; 21-0136I_T1633-4_MXM-M; Mfr Part MAX98357AETE+T; LCSC Part C910544
U2: ESP32-S3-WROOM-1
U3: OV5640; TE_2-1734839-4_1x24-1MP_P0.5mm_Horizontal; Mfr Part AFC01-S24FCA-00; LCSC Part C262669
U4: 24Mhz; YSO110TR; Mfr Part OT252024MJBA4SL; LCSC Part C669072
U5: AXP2101; QFN-40-1EP_5x5mm_P0.4mm_EP3.6x3.6mm; Mfr Part AXP2101; LCSC Part C3036461

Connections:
+1V5: U3.10 (DVDD), U5.18 (ALDO1)
+2V8: C11.1, C12.1, U3.4 (AVDD), U5.19 (ALDO2)
+3V3: 3v3J1.2, C2.1, C3.1, C4.1, C5.1, C10.1, C23.2, C24.2, C29.1, C31.1, J2.2, MK2.5 (VDD), NC5.2, R1.1, R7.2, R8.2, R9.2, R10.2, R12.1, R13.1, R14.1, R15.1, U2.2 (3V3), U3.11 (DOVDD), U4.4 (VDD)
BCLK_AMP: U1.16 (BCLK), U2.21 (IO13)
BCLK_MIC: MK2.4 (SCK), U2.26 (IO45)
CAM_CLKINTRNL: C33.1, JP1.1 (A), U4.3 (OUT)
CAM_HREF: U2.14 (IO20), U3.9 (HREF)
CAM_MCLK: JP1.3 (B), U2.12 (IO8)
CAM_PCLK: C9.1, U2.9 (IO16), U3.17 (PCLK)
CAM_PWDN: NC1.1, U2.15 (IO3), U3.8 (PWDN)
CAM_RESET: NC3.2, U2.35 (IO42), U3.6 (RESET)
CAM_SCL: JP5.2 (C), R9.1, U2.17 (IO9), U3.5 (SCL)
CAM_SDA: JP6.2 (C), R8.1, U2.18 (IO10), U3.3 (SDA)
CAM_VSYNC: U2.34 (IO41), U3.7 (VSYNC)
CAM_Y2: U2.7 (IO7), U3.19 (Y2)
CAM_Y3: U2.5 (IO5), U3.21 (Y3)
CAM_Y4: U2.4 (IO4), U3.22 (Y4)
CAM_Y5: U2.6 (IO6), U3.20 (Y5)
CAM_Y6: U2.8 (IO15), U3.18 (Y6)
CAM_Y7: U2.10 (IO17), U3.16 (Y7)
CAM_Y8: U2.11 (IO18), U3.14 (Y8)
CAM_Y9: U2.13 (IO19), U3.12 (Y9)
EN: C1.1, J2.6, R1.2, U2.3 (EN)
GND: 3v3J1.1, 3v3J2.1, BAT1.1, C1.2, C2.2, C3.2, C4.2, C5.2, C6.2, C7.2, C8.2, C9.2, C10.2, C11.2, C12.2, C13.2, C14.1, C15.1, C16.1, C17.1, C18.1, C19.1, C20.2, C21.1, C22.2, C23.1, C24.1, C25.1, C26.1, C27.2, C28.2, C29.2, C30.2, C31.2, C32.1, C33.2, C34.2, D4.3 (VSS), J2.1, JP4.1 (A), MK2.3 (GND), NC1.2, NC2.1, P1.A1 (GND), P1.A12 (GND), P1.B1 (GND), P1.B12 (GND), R2.1, R3.2, R16.2, SW1.1, SW2.1, SW4.1, SW5.1, U1.3 (GND), U1.11 (GND), U1.15 (GND), U2.1 (GND), U2.40 (GND), U2.41 (GND), U3.2 (AGND), U3.15 (DGND), U4.2 (GND), U5.3 (GND), U5.41 (EP)
GPIO0: J2.5, U2.27 (IO0)
GPIO46: J2.4, U2.16 (IO46)
I2SDAT_AMP: U1.1 (DIN), U2.31 (IO38)
I2SDAT_MIC: R4.1, U2.32 (IO39)
LEDCNTRL: R5.2, U2.19 (IO11)
unnamed: C13.1, NC3.1, R7.1
unnamed: D1.2 (A), R11.1
unnamed: D1.1 (K), U5.1 (CHGLED)
unnamed: D4.4 (DIN), R5.1
unnamed: JP1.2 (C), U3.13 (MCLK)
unnamed: C34.1, JP2.1 (A), R13.2, SW4.2
unnamed: JP3.1 (A), U2.25 (IO48)
unnamed: JP4.2 (B), U1.2 (GAIN_SLOT)
unnamed: MK2.2 (LR), R2.2
unnamed: MK2.6 (SD), R3.1, R4.2
unnamed: P1.S1 (SHIELD), R16.1
unnamed: C19.2, L1.2, NC5.1, U5.21 (FB1)
unnamed: L1.1, U5.22 (LX1)
unnamed: L2.2, U5.35 (SW)
unnamed: NC2.2, U5.31 (TS)
unnamed: C32.2, U5.36 (VMID)
unnamed: C14.2, U5.2 (VREF)
PMIC_IRQ: R10.1, U2.33 (IO40), U5.38 (IRQ)
PMIC_PWRON: JP2.2 (B), JP3.2 (B), U5.30 (PWRON)
PMIC_SCL: J2.9, JP5.1 (A), JP6.1 (A), U5.40 (SCK)
PMIC_SDA: J2.10, JP5.3 (B), JP6.3 (B), U5.39 (SDA)
RXD: J2.7, U2.36 (RXD0)
SDMODE_AMP: U1.4 (~SD_MODE), U2.22 (IO14)
SPK_N: J1.1, U1.10 (OUTN)
SPK_P: J1.2, U1.9 (OUTP)
SW_L1: C30.1, R15.2, SW5.2, U2.24 (IO47)
SW_L2: C28.1, R14.2, SW2.2, U2.38 (IO2)
SW_L3: C27.1, R12.2, SW1.2, U2.39 (IO1)
TXD: J2.8, U2.37 (TXD0)
VBAT: BAT1.2, U5.33 (BAT)
VBUS: C15.2, P1.A4 (VBUS), P1.A9 (VBUS), P1.B4 (VBUS), P1.B9 (VBUS), U5.37 (VBUS)
VSYS: 3v3J2.2, C6.1, C7.1, C8.1, C16.2, C17.2, C18.2, C20.1, C21.2, C22.1, C25.2, C26.2, D4.1 (VDD), J2.3, L2.1, R11.2, U1.7 (VDD), U1.8 (VDD), U5.17 (ALDOIN), U5.23 (VIN1), U5.34 (VSYS)
WS_AMP: U1.14 (LRCLK), U2.20 (IO12)
WS_MIC: MK2.1 (WS), U2.23 (IO21)

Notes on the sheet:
ESP32 Main Board
PMIC Board
Color LED Board
Switch Board
Amp Board
MIC Board
CAM Board

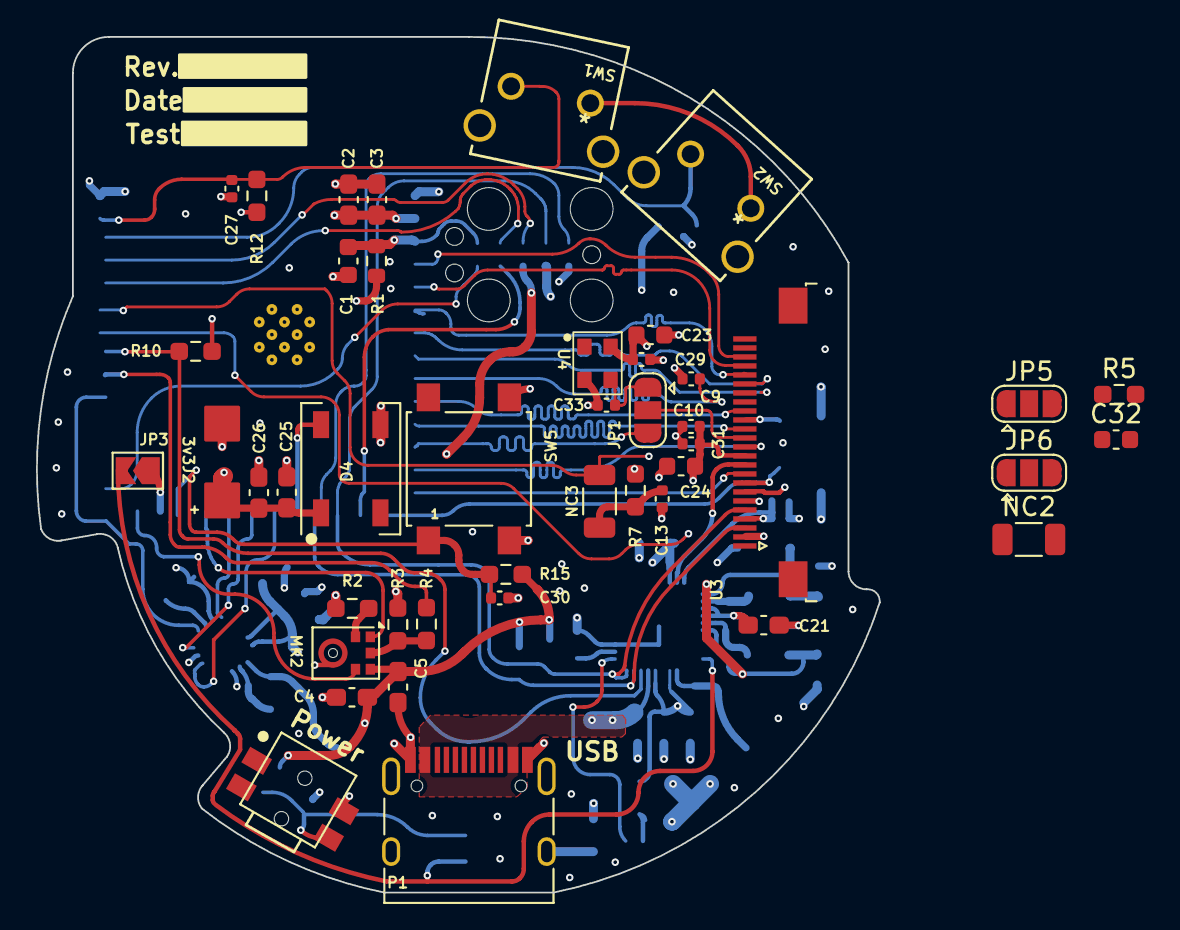
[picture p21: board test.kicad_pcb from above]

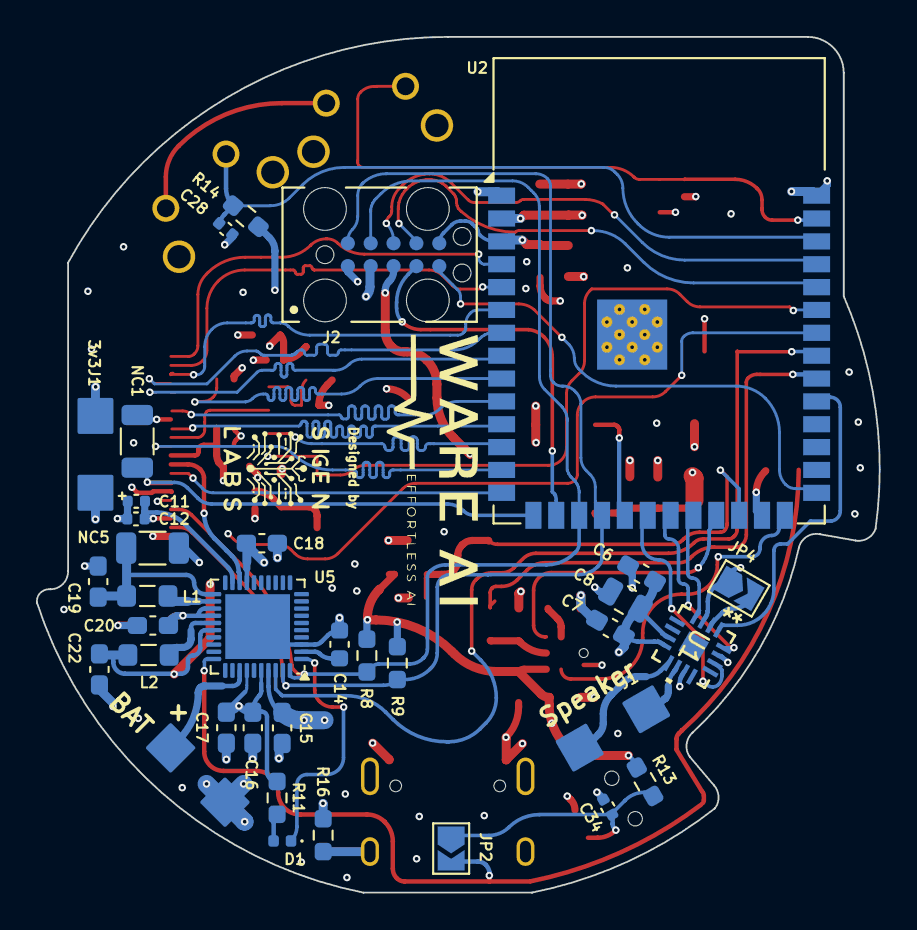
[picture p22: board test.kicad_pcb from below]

Board: 4 copper layers, 46.8 x 47.5 mm, 79 parts (35 on the bottom side), 63 nets.

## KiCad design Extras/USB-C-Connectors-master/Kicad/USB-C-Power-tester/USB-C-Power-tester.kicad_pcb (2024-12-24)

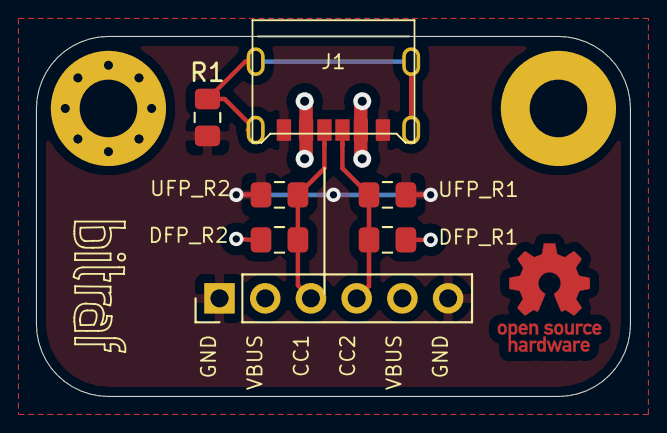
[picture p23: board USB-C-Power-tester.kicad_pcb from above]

Board: 2 copper layers, 33.0 x 20.0 mm, 11 parts (0 on the bottom side), 5 nets.

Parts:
DFP_R1, DFP_R2: DFP; R_0805_2012Metric_Pad1.15x1.40mm_HandSolder
H1: MountingHole; MountingHole_3.2mm_M3_Pad_Via
H3: MountingHole; MountingHole_3.2mm_M3_Pad
J1: USB_C_Receptacle_USB2.0; TYPE-C-31-M-17
L1: Logo_Open_Hardware_Small; OSHW-Logo_5.7x6mm_Copper
L2: Logo_Open_Hardware_Small; Bitraf_logo_3.0_x_7.5_mm
PIN1: Screw_Terminal_01x06; PinHeader_1x06_P2.54mm_Vertical
R1: 1M; R_0805_2012Metric_Pad1.15x1.40mm_HandSolder
UFP_R1, UFP_R2: UFP; R_0805_2012Metric_Pad1.15x1.40mm_HandSolder

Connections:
GND: J1.A12, J1.B12, PIN1.1, PIN1.6, R1.1, UFP_R1.2, UFP_R2.2
unnamed: DFP_R1.1, J1.A5, PIN1.4, UFP_R1.1
unnamed: DFP_R2.1, J1.B5, PIN1.3, UFP_R2.1
unnamed: J1.S1, R1.2
VBUS: DFP_R1.2, DFP_R2.2, J1.A9, J1.B9, PIN1.2, PIN1.5

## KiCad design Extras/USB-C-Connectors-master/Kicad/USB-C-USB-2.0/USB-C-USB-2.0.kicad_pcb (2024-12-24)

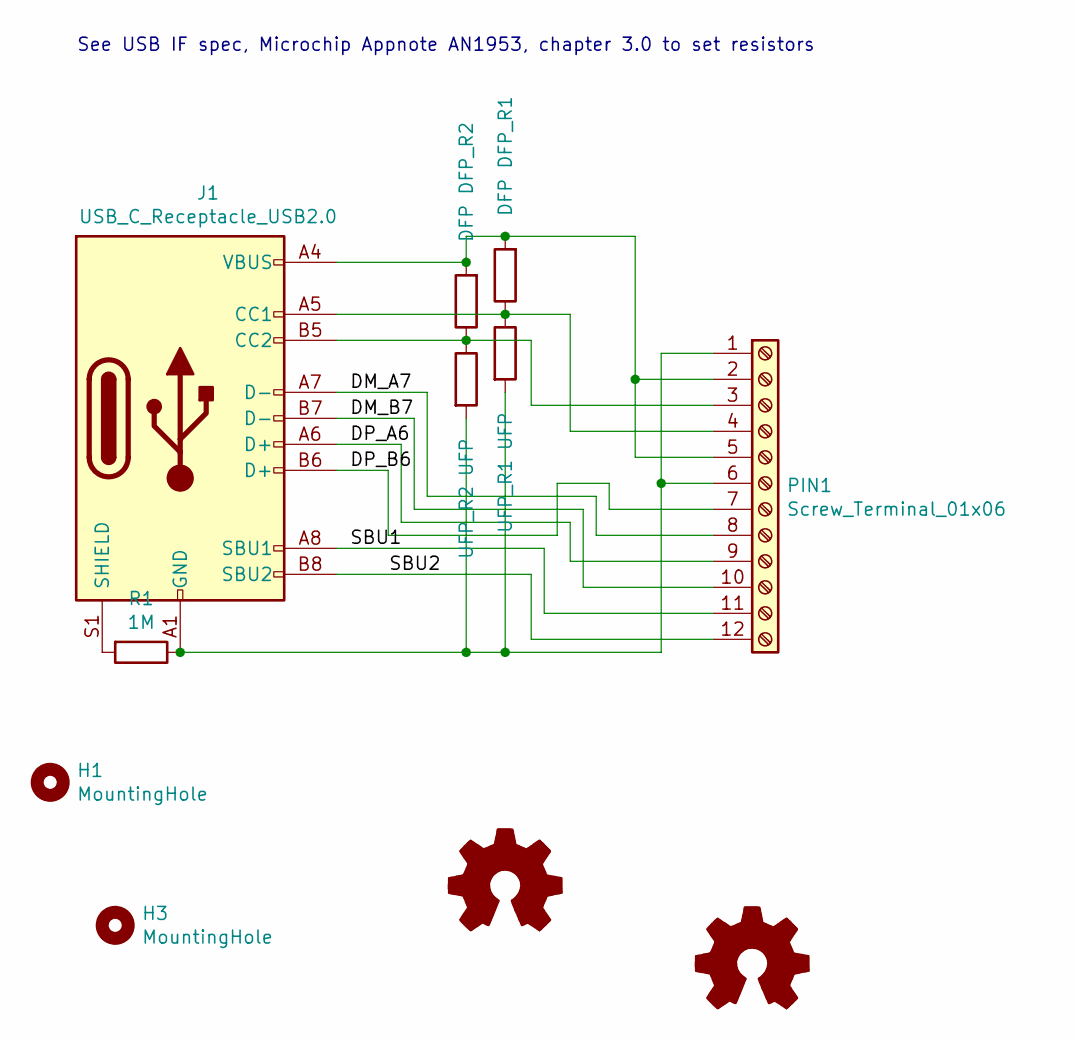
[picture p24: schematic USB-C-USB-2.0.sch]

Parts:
DFP_R1, DFP_R2: DFP; R_0805_2012Metric_Pad1.15x1.40mm_HandSolder
H1: MountingHole; MountingHole_3.2mm_M3_Pad_Via
H3: MountingHole; MountingHole_3.2mm_M3_Pad
J1: USB_C_Receptacle_USB2.0; TYPE-C-31-M-12; MPN TYPE-C-31-M-17
L1: Logo_Open_Hardware_Small; OSHW-Logo_5.7x6mm_SilkScreen
L2: Logo_Open_Hardware_Small; Bitraf_logo_3.0_x_7.5_mm
PIN1: Screw_Terminal_01x06; PinHeader_1x12_P2.54mm_Vertical
R1: 1M; R_0805_2012Metric_Pad1.15x1.40mm_HandSolder
UFP_R1, UFP_R2: UFP; R_0805_2012Metric_Pad1.15x1.40mm_HandSolder

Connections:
/DM_A7: J1.A7 (D-), PIN1.8
/DM_B7: J1.B7 (D-), PIN1.10
/DP_A6: J1.A6 (D+), PIN1.9
/DP_B6: J1.B6 (D+), PIN1.7
/SBU1: J1.A8 (SBU1), PIN1.11
/SBU2: J1.B8 (SBU2), PIN1.12
GND: J1.A1 (GND), J1.A12 (GND), J1.B1 (GND), J1.B12 (GND), PIN1.1, PIN1.6, R1.1, UFP_R1.2, UFP_R2.2
unnamed: DFP_R1.1, J1.A5 (CC1), PIN1.4, UFP_R1.1
unnamed: DFP_R2.1, J1.B5 (CC2), PIN1.3, UFP_R2.1
unnamed: J1.S1 (SHIELD), R1.2
VBUS: DFP_R1.2, DFP_R2.2, J1.A4 (VBUS), J1.A9 (VBUS), J1.B4 (VBUS), J1.B9 (VBUS), PIN1.2, PIN1.5

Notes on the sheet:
See USB IF spec, Microchip Appnote AN1953, chapter 3.0 to set resistors

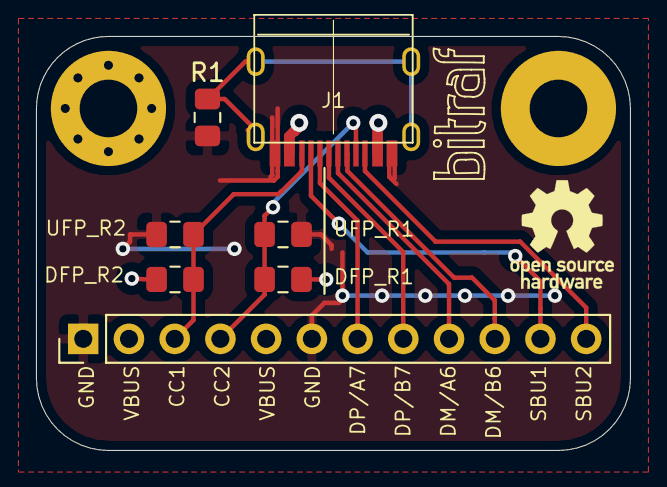
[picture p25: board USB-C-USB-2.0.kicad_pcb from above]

Board: 2 copper layers, 33.0 x 23.0 mm, 11 parts (0 on the bottom side), 11 nets.

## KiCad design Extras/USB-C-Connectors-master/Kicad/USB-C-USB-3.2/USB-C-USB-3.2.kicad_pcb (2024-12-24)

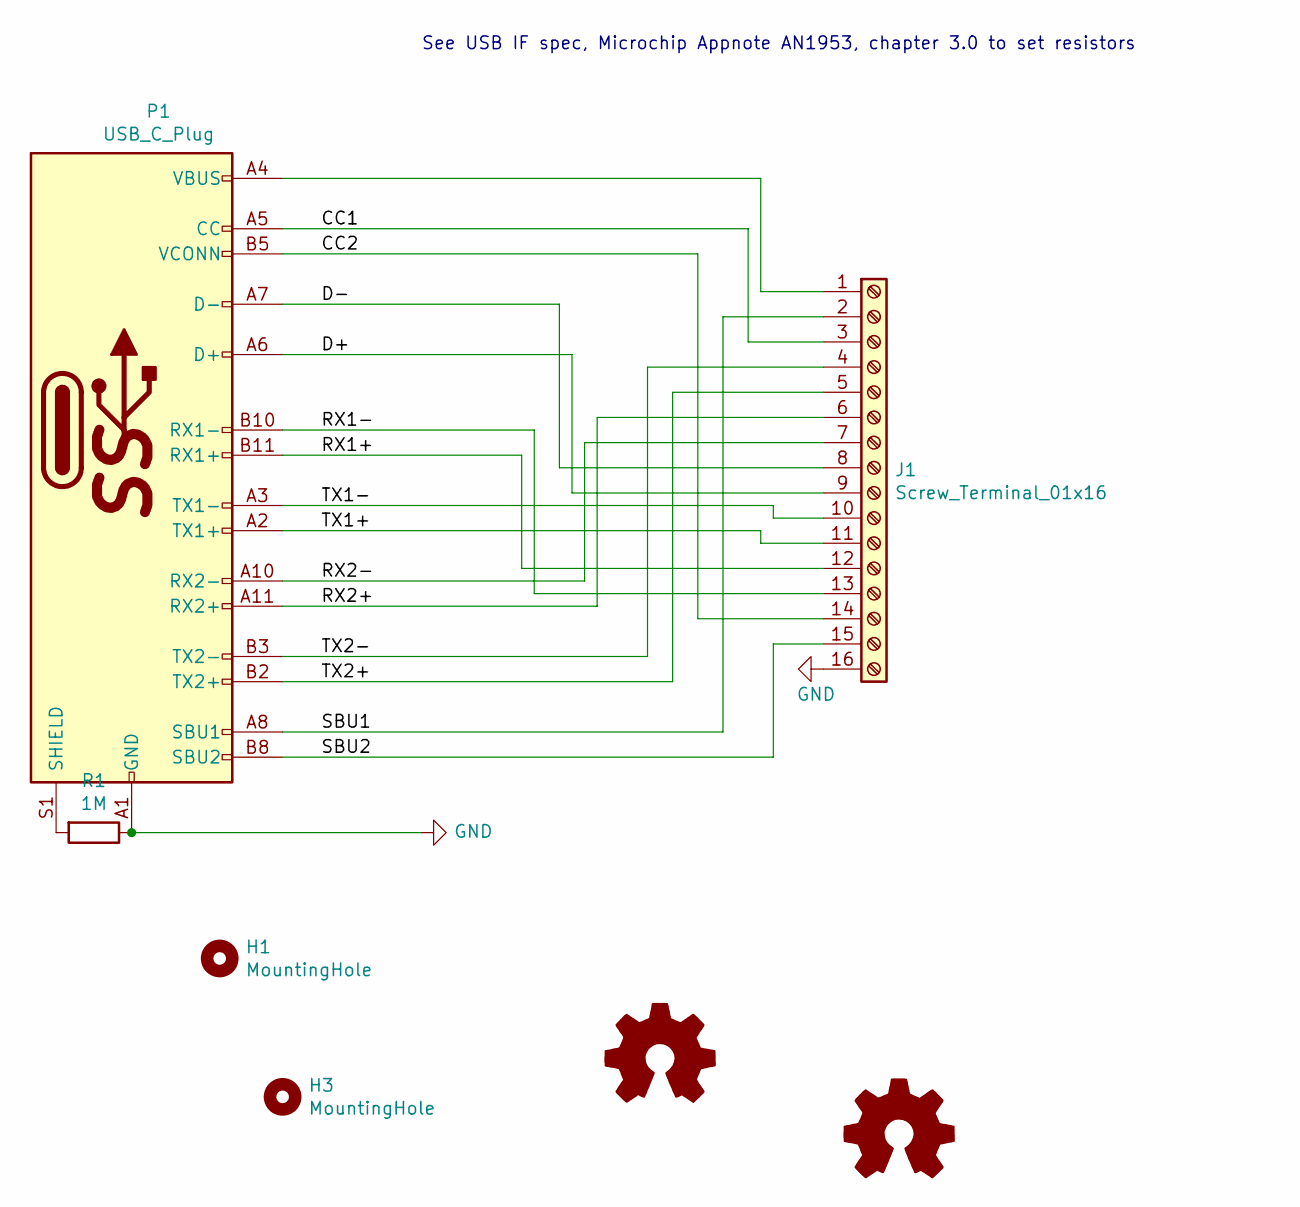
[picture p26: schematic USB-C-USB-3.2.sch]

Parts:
H1: MountingHole; MountingHole_3.2mm_M3_Pad_Via
H3: MountingHole; MountingHole_3.2mm_M3_Pad
J1: Screw_Terminal_01x16; PinHeader_1x16_P2.54mm_Vertical
L1: Logo_Open_Hardware_Small; OSHW-Logo_5.7x6mm_Copper
L2: Logo_Open_Hardware_Small; Bitraf_logo_3.0_x_7.5_mm
P1: USB_C_Plug; USB_C_Receptacle_Amphenol_12401548E4-2A
R1: 1M; R_0805_2012Metric_Pad1.15x1.40mm_HandSolder

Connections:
/CC1: J1.3, P1.A5 (CC)
/CC2: J1.14, P1.B5 (VCONN)
/D+: J1.9, P1.A6 (D+)
/D-: J1.8, P1.A7 (D-)
/RX1+: J1.12, P1.B11 (RX1+)
/RX1-: J1.13, P1.B10 (RX1-)
/RX2+: J1.6, P1.A11 (RX2+)
/RX2-: J1.7, P1.A10 (RX2-)
/SBU1: J1.2, P1.A8 (SBU1)
/SBU2: J1.15, P1.B8 (SBU2)
/TX1+: J1.11, P1.A2 (TX1+)
/TX1-: J1.10, P1.A3 (TX1-)
/TX2+: J1.5, P1.B2 (TX2+)
/TX2-: J1.4, P1.B3 (TX2-)
GND: J1.16, P1.A1 (GND), P1.A12 (GND), P1.B1 (GND), P1.B12 (GND), R1.1
unnamed: P1.S1 (SHIELD), R1.2
VBUS: J1.1, P1.A4 (VBUS), P1.A9 (VBUS), P1.B4 (VBUS), P1.B9 (VBUS)

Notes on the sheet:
See USB IF spec, Microchip Appnote AN1953, chapter 3.0 to set resistors

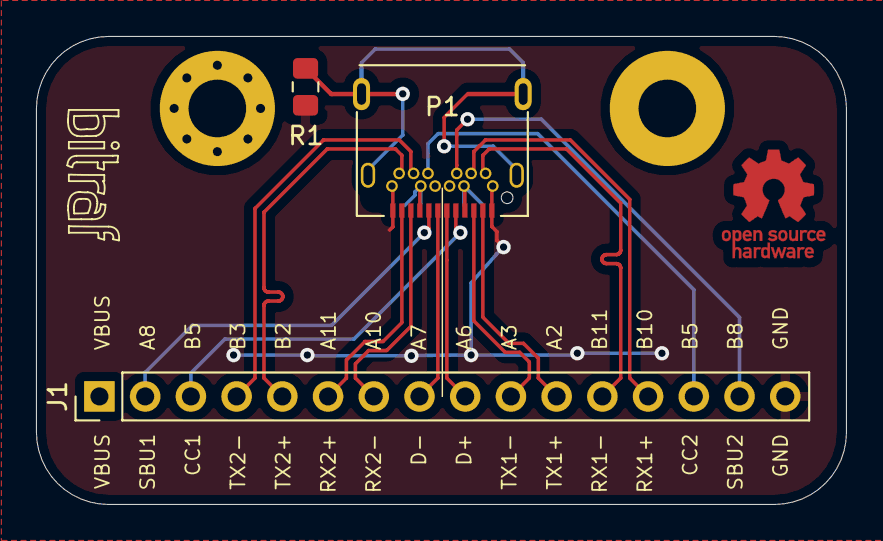
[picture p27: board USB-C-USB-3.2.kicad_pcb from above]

Board: 2 copper layers, 45.0 x 26.0 mm, 7 parts (0 on the bottom side), 17 nets.

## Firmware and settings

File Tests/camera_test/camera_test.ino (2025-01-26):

#include <Wire.h>
#include "esp_camera.h"
#include <WiFi.h>
#include <ESPAsyncWebServer.h>
#include <AsyncTCP.h>

#define AXP2101_ADDRESS 0x34
#define I2C_SDA 10
#define I2C_SCL 9
#define AXP_IRQ 40


//device we have is : Espressif Systems ESP32-S3-WROOM-1-N16R2 , 16MBQuadSPI,2MB PSRAM

const char* ssid = "iobeam";
const char* password = "12345678";

AsyncWebServer server(80);

#define CAMERA_MODEL_ESP32_CAM_BOARD

#include "ESP32_OV5640_AF.h"

#define I2C_SDA 10
#define I2C_SCL 9

// ESP32 AI-THINKER Board
#define PWDN_GPIO_NUM 3
#define RESET_GPIO_NUM 42
#define XCLK_GPIO_NUM 8
#define SIOD_GPIO_NUM I2C_SDA
#define SIOC_GPIO_NUM I2C_SCL
#define Y9_GPIO_NUM 19
#define Y8_GPIO_NUM 18
#define Y7_GPIO_NUM 17
#define Y6_GPIO_NUM 15
#define Y5_GPIO_NUM 6
#define Y4_GPIO_NUM 4
#define Y3_GPIO_NUM 5
#define Y2_GPIO_NUM 7
#define VSYNC_GPIO_NUM 41
#define HREF_GPIO_NUM 20
#define PCLK_GPIO_NUM 16


static camera_config_t camera_config = {
  .pin_pwdn  = PWDN_GPIO_NUM,
  .pin_reset = RESET_GPIO_NUM,
  .pin_xclk = XCLK_GPIO_NUM,
  .pin_sscb_sda = SIOD_GPIO_NUM,
  .pin_sscb_scl = SIOC_GPIO_NUM,

  .pin_d7 = Y9_GPIO_NUM,
  .pin_d6 = Y8_GPIO_NUM,
  .pin_d5 = Y7_GPIO_NUM,
  .pin_d4 = Y6_GPIO_NUM,
  .pin_d3 = Y5_GPIO_NUM,
  .pin_d2 = Y4_GPIO_NUM,
  .pin_d1 = Y3_GPIO_NUM,
  .pin_d0 = Y2_GPIO_NUM,
  .pin_vsync = VSYNC_GPIO_NUM,
  .pin_href = HREF_GPIO_NUM,
  .pin_pclk = PCLK_GPIO_NUM,

  //XCLK 20MHz or 10MHz for OV2640 double FPS (Experimental)
  .xclk_freq_hz = 20000000,
  .ledc_timer = LEDC_TIMER_0,
  .ledc_channel = LEDC_CHANNEL_0,

  .pixel_format = PIXFORMAT_JPEG,//YUV422,GRAYSCALE,RGB565,JPEG
  .frame_size = FRAMESIZE_QVGA,//QQVGA-QXGA Do not use sizes above QVGA when not JPEG

  .jpeg_quality = 20, //0-63 lower number means higher quality
  .fb_count = 1 //if more than one, i2s runs in continuous mode. Use only with JPEG
};

void initAXP2101() {

  // DONT PLAY WITH FIRE, CHANGE BELOW VALUES IF YOU KNOW WHAT YOU ARE DOING
  //set batfet value to on
  Wire.beginTransmission(AXP2101_ADDRESS);
  Wire.write(18);
  Wire.write(8);
  Wire.endTransmission();


  // set rbfet charger current limit to 0.9A
  Wire.beginTransmission(AXP2101_ADDRESS);
  Wire.write(22);
  Wire.write(2);
  Wire.endTransmission();



  // change vsys min threshold voltage 3.3V
  Wire.beginTransmission(AXP2101_ADDRESS);
  Wire.write(36);
  Wire.write(7);
  Wire.endTransmission();


  //change vindpm to 4.25V max lipo voltage
  Wire.beginTransmission(AXP2101_ADDRESS);
  Wire.write(21);
  Wire.write(4); //change to 15 if necessary
  Wire.endTransmission();

  // Start writing aldo1 value
  Wire.beginTransmission(AXP2101_ADDRESS);
  Wire.write(146);
  Wire.write(9);
  Wire.endTransmission();

  // Start writing aldo2 value
  Wire.beginTransmission(AXP2101_ADDRESS);
  Wire.write(147);
  Wire.write(23);
  Wire.endTransmission();

  // Start writing dcdc1 value
  Wire.beginTransmission(AXP2101_ADDRESS);
  Wire.write(130);
  Wire.write(18);
  Wire.endTransmission();

  //enable dcdc1
  Wire.beginTransmission(AXP2101_ADDRESS);
  Wire.write(128);
  Wire.write(1);
  Wire.endTransmission();

  //enable aldos 1 and 2
  Wire.beginTransmission(AXP2101_ADDRESS);
  Wire.write(144);
  Wire.write(3);
  Wire.endTransmission();


  //set ONLEVEL 2 s , OFFLEVEL 4 s and IRQ level as 1s
  Wire.beginTransmission(AXP2101_ADDRESS);
  Wire.write(39);
  Wire.write(14);
  Wire.endTransmission();
}


esp_err_t camera_init() {
  //power up the camera if PWDN pin is defined
  if (PWDN_GPIO_NUM != -1) {
    pinMode(PWDN_GPIO_NUM, OUTPUT);
    digitalWrite(PWDN_GPIO_NUM, LOW);

    pinMode(PWDN_GPIO_NUM, OUTPUT);
    digitalWrite(PWDN_GPIO_NUM, LOW);
  }

  //initialize the camera
  esp_err_t err = esp_camera_init(&camera_config);
  if (err != ESP_OK) {
    Serial.print( "Camera Init Failed");
    return err;
  }

  return ESP_OK;
}

esp_err_t camera_capture() {
  //acquire a frame
  camera_fb_t * fb = esp_camera_fb_get();
  if (!fb) {
    Serial.println( "Camera Capture Failed");
    return ESP_FAIL;
  }
  //replace this with your own function
  Serial.print("got it");

  //return the frame buffer back to the driver for reuse
  esp_camera_fb_return(fb);
  return ESP_OK;
}



void setup() {
  Serial.begin(115200);
  Serial.println("Starting PMIC configurations");
  Wire.begin(I2C_SDA, I2C_SCL);

  delay(100);
  initAXP2101();
  delay (100); //wait for sometime for the voltages to stabilize

  Serial.println("Starting Camera");
  camera_init();
  Serial.println("Starting Capture");

  WiFi.begin(ssid, password);
  while (WiFi.status() != WL_CONNECTED) {
    delay(1000);
    Serial.println("Connecting to WiFi...");
  }
  Serial.println("Connected to WiFi");

  //Print the IP address
  Serial.println("IP address: ");
  Serial.println(WiFi.localIP());

  Serial.println("HTTP server started");

  server.on("/", HTTP_GET, [](AsyncWebServerRequest * request)
  {
    camera_fb_t * fb = esp_camera_fb_get();
    if (!fb) {
      Serial.println( "Camera Capture Failed");
      request->send(200, "text/plain", "F no!");
    } else {
      //replace this with your own function

      AsyncResponseStream *response = request->beginResponseStream("image/jpg", fb->len);
      response->write(fb->buf, fb->len);
      request->send(response);

      Serial.print("wrote it");
      //request->send(200, "text/plain", "Hello AsyncWebServer!");
    }
    //return the frame buffer back to the driver for reuse
    esp_camera_fb_return(fb);
  });
  server.begin();

}

void loop() {
  // put your main code here, to run repeatedly:

}

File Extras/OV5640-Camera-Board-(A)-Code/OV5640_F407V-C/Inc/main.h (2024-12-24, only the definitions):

#define WAKE_UP_KEY_Pin GPIO_PIN_0
#define WAKE_UP_KEY_GPIO_Port GPIOA
#define OV5640_PWDN_Pin GPIO_PIN_2
#define OV5640_PWDN_GPIO_Port GPIOA
#define USER_KEY_Pin GPIO_PIN_1
#define USER_KEY_GPIO_Port GPIOB
#define OV5640_SIOC_Pin GPIO_PIN_10
#define OV5640_SIOC_GPIO_Port GPIOB
#define OV5640_SIOD_Pin GPIO_PIN_11
#define OV5640_SIOD_GPIO_Port GPIOB

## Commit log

2024-12-09 Created Kicad project
    [test.kicad_pcb, test.kicad_sch]
2024-12-10 created folder structures
    [test.kicad_pcb, test.kicad_sch]
2024-12-10 Added esp32 consideration
2024-12-10 Implemented Esp32 circuits
    [ICS-43434.step, test.kicad_sch]
2024-12-10 Implemented Amplifier
    [test.kicad_sch]
2024-12-15 Implemented ov5640
    [test.kicad_sch]
2024-12-16 Schematic finished
    [test.kicad_sch]
2024-12-16 Added Battery plugin in schematic
    [test.kicad_sch]
2024-12-17 Started PCB Layout designs
    [test.kicad_pcb, test.kicad_sch]
2024-12-17 Placed components on PCB
    [test.kicad_pcb, test.kicad_sch]
2024-12-18 updated schematic symbols
2024-12-24 Added Clock for Camera
    [USB-C-Power-tester-B_Cu.gbr, USB-C-Power-tester-B_Mask.gbr, USB-C-Power-tester-B_Paste.gbr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]
2024-12-24 3d Model Casing and PCB Added
    [Ware_lid.STL, Ware_outer_shell.STL, test.kicad_pcb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]
2024-12-24 Floorplanning done
    [test.kicad_pcb, test.kicad_sch]
2024-12-24 Started PCB routing
    [test.kicad_pcb, test.kicad_sch]
2024-12-26 Updated schematics
    [test.kicad_pcb, test.kicad_sch]
2024-12-26 Updated PCB floor
    [test.kicad_pcb]
2024-12-26 PCB updated
    [AFC01-S24FCA-00.stp, TC2050-IDC.step, test.kicad_pcb]
2024-12-26 Checked schematic and PCB
    [test.kicad_pcb, test.kicad_sch]
2024-12-29 Rerouted pin connections on esp32
    [test.kicad_pcb, test.kicad_sch]
2024-12-29 Connected a missing piece
    [test.kicad_pcb, test.kicad_sch]
2024-12-29 DRC Corrections done on schematic
    [test.kicad_pcb]
2025-01-02 50% Routing Done
    [c-1825027-8-g-3d.stp, test.kicad_pcb, test.kicad_sch]
2025-01-04 Mouting hole Added
    [test.kicad_pcb]
2025-01-06 ROUTED MORE
    [test.kicad_pcb, test.kicad_sch]
2025-01-06 ROUTED camera
    [test.kicad_pcb]
2025-01-06 Routing 80% Done
    [test-B_Cu.gbr, test-B_Mask.gbr, test-B_Paste.gbr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]
2025-01-06 Routing 95% done
    [test.kicad_pcb, test.kicad_sch]
2025-01-07 Exposed i2c pads of camera and pmic too and finished routing
    [test.kicad_pcb, test.kicad_sch]
2025-01-07 Zones created Finished Routing
    [test.kicad_pcb, test.kicad_sch]
2025-01-07 Finished layouts and offsetting
    [test.kicad_pcb, test.kicad_sch]
2025-01-07 Routing completed
    [test.kicad_pcb]
2025-01-08 Mounting Hole added
    [test.kicad_pcb]
2025-01-09 Optimizing for DFM still pending
    [test-B_Cu.gbr, test-B_Mask.gbr, test-B_Paste.gbr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]
2025-01-09 DFM completed Logo added
    [BOM List.csv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]
2025-01-09 CPL file updated as Per JLCPcb requirements
    [test-all-pos.csv]
2025-01-09 Via Size update 0.2 mm drill 0.4 mm diameter
    [test-B_Cu.gbr, test-B_Mask.gbr, test-B_Paste.gbr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]
2025-01-09 Updated Via Size
    [test-B_Cu.gbr, test-B_Mask.gbr, test-B_Paste.gbr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]
2025-01-14 Redone footprint of Component Crystal
    [test.kicad_pcb]
2025-01-14 Updated Orientations
    [BOM List.csv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]
2025-01-26 Finished REV1 Design and created pcb
    [BOM List.csv, BOMList.csv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]
2025-01-26 Finished Rev2 Schematic
    [BOM List.csv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]

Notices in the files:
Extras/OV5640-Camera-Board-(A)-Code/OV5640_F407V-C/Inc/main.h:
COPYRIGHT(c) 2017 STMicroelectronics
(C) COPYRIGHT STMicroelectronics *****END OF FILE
